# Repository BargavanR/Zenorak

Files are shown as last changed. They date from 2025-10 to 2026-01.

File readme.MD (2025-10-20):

ZENORAK_ROS2_CONTROL PACKAGE:

### Package Structure

zenorak_ros2_control/
├── config/
│ ├── controller.yaml # Controller configuration
├── description/
│ └── zenorak.xacro # Robot URDF description
├── launch/
│ ├── launch_robot.launch.py # Main robot launch file
│ └── rsp.launch.py # Robot state publisher launch
├── meshes/
│ ├── collision/ # Collision meshes
│ └── visual/ # Visual meshes
└── rviz/
└── default.rviz # RViz visualization config

## Key Components

### 1. Robot Description (`zenorak.xacro`) - Defines the physical structure of the rover:

- **Base Link**: Main chassis with mass of \_\_ kg
- **Four Wheels**: Each wheel with individual inertial properties
  - Front Left Wheel
  - Front Right Wheel
  - Rear Left Wheel
  - Rear Right Wheel
- **Joint Configuration**: Continuous joints for wheel rotation
- **Hardware Interface**: Configured for Arduino-based differential drive control

### 2. Robot State Publisher (`rsp.launch.py`) - Processes the Xacro file and publishes robot state information:

- Converts Xacro to URDF format
- Publishes TF (transform) tree for all robot links
- Provides `/robot_description` topic for visualization
- Essential for RViz and navigation stack integration

**Key Functions:**

- Reads `zenorak.xacro` from the description folder
- Processes macros into complete URDF
- Launches `robot_state_publisher` node with robot description

### 3. Main Launch File (`launch_robot.launch.py`) - Orchestrates the complete robot system startup with coordinated timing:

**Launch Sequence:**

1. **Robot State Publisher** (Immediate) - Publishes robot URDF and transforms
2. **Controller Manager** (3-second delay)

   - Manages hardware interface to Arduino
   - Loads controller configurations
   - Provides real-time control loop

3. **Differential Drive Controller** (After Controller Manager)

   - Accepts `/cmd_vel` commands
   - Controls front left and right wheels
   - Publishes odometry data

4. **Joint State Broadcaster** (After Controller Manager)
   - Publishes joint positions and velocities
   - Enables state monitoring and visualization

### 4. RViz Configuration (`default.rviz`)

Pre-configured visualization setup:

- Robot model display with collision/visual meshes
- Grid reference frame
- TF tree visualization
- Interactive tools for pose setting and measurements
- Fixed frame: `base_link`
- Orbit camera view for optimal robot observation

### Launching the Robot

# Launch complete robot system

ros2 launch zenorak_ros2_control launch_robot.launch.py

This command will:

1. Start robot state publisher
2. Initialize hardware interface (after 3-second delay)
3. Spawn differential drive controller
4. Spawn joint state broadcaster

### Controlling the Robot - Send velocity commands to the robot:

# Move forward

ros2 topic pub /diff_cont/cmd_vel_unstamped geometry_msgs/msg/Twist "{linear: {x: 0.5}, angular: {z: 0.0}}"

# Rotate in place

ros2 topic pub /diff_cont/cmd_vel_unstamped geometry_msgs/msg/Twist "{linear: {x: 0.0}, angular: {z: 0.5}}"

### Visualizing in RViz

# Launch RViz with default configuration

ros2 run rviz2 rviz2 -d $(ros2 pkg prefix zenorak_ros2_control)/share/zenorak_ros2_control/rviz/default.rviz

### Monitoring Robot State

# Check joint states

ros2 topic echo /joint_states

# Check odometry

ros2 topic echo /diff_cont/odom

# List all active controllers

ros2 control list_controllers

## Dependencies

- ROS 2 (Humble or later recommended)
- `ros2_control` and `ros2_controllers`
- `robot_state_publisher`
- `xacro`
- `rviz2`
- `diffdrive_arduino` hardware plugin
- `controller_manager`

ZENORAK_TELEOP PACKAGE:

## Features

- **Keyboard Control**: Use W, A, S, D keys for intuitive robot movement
- **Incremental Commands**: Sends progressive command values (0-120) at 1Hz
- **Non-blocking Input**: Reads keyboard in a separate thread without blocking ROS operations
- **Clean Termination**: Graceful shutdown with proper terminal restoration

## Package Structure

zenorak_teleop/
├── scripts/
│ └── zenorak_teleop.py # Main teleoperation node
├── launch/
│ └── teleop.launch.py # Launch file
├── CMakeLists.txt # Build configuration
└── package.xml # Package metadata

### Command Protocol - The node publishes to the `zenorak_teleop_cmd` topic with the following format:

| Key | Command Prefix | Direction | Example Messages |
| ----- | --- | --- | --- |
| W | `f` | Forward | `f0`, `f1`, ... `f120` |
| A | `l` | Left | `l0`, `l1`, ... `l120` |
| S | `b` | Backward  | `b0`, `b1`, ... `b120` |
| D | `r` | Right | `r0`, `r1`, ... `r120` |
| Enter | `s` | Stop | `s0` |

### Operation Flow

1. **Key Press Detection**: Continuously reads keyboard input in raw mode (no Enter needed)
2. **Counter Increment**: When a key (W/A/S/D) is held, counter increments from 0 to 120
3. **Message Publishing**: Publishes command at 1Hz (every second) while key is active
4. **Stop Command**: Pressing Enter sends `s0` and resets the system

### Dependencies

# ROS 2 packages

sudo apt install ros-<distro>-rclpy ros-<distro>-std-msgs

### Building

cd ~/ros2_ws
colcon build --packages-select zenorak_teleop
source install/setup.bash

### Method 1: Using ros2 run

ros2 run zenorak_teleop zenorak_teleop.py

### Method 2: Using Launch File

ros2 launch zenorak_teleop teleop.launch.py

### Methods Explained

**`_read_keys()`**

- Runs in separate thread
- Reads single characters from stdin
- Updates `active_key` when W/A/S/D pressed
- Sends stop command on Enter

**`_tick()`**

- Called every 1 second by ROS timer
- Publishes command if key is active
- Increments counter (0 → 120)
- Stops incrementing at 120

**`destroy_node()`**

- Stops keyboard thread
- Restores terminal settings
- Cleans up resources

ZENORAK_SERIAL PACKAGE:

## Package Structure

zenorak_serial/
├── scripts/
│ └── zenorak_serial.py # Serial bridge node
├── CMakeLists.txt # Build configuration
└── package.xml # Package metadata

### Message Processing

1. **Subscribe**: Listens to `/zenorak_teleop_cmd` topic
2. **Extract**: Gets command string from ROS message (e.g., "f25")
3. **Format**: Adds newline character for Arduino's `readStringUntil('\n')`
4. **Transmit**: Sends via serial to `/dev/ttyACM0` at 115200 baud
5. **Log**: Records successful transmission for debugging

### Serial Protocol

**Examples:**

- `f25\n` → Forward command, intensity 25
- `l10\n` → Left turn, intensity 10
- `s0\n` → Stop command

## Installation & Setup

### Dependencies

# ROS 2 packages

sudo apt install ros-<distro>-rclpy ros-<distro>-std-msgs

# Python serial library

sudo apt install python3-serial

# OR

pip3 install pyserial

### Starting the Bridge

ros2 run zenorak_serial zenorak_serial.py

### Testing Communication

**Terminal 1: Start the bridge**

```bash
ros2 run zenorak_serial zenorak_serial.py
```

**Terminal 2: Send test command**

```bash
ros2 topic pub /zenorak_teleop_cmd std_msgs/msg/String "{data: 'f50'}"
```

## Full Workflow

### 1. Hardware Setup

```bash
# Connect Arduino via USB
# Upload control firmware to Arduino
# Verify connection: ls /dev/ttyACM0
```

### 2. Launch Main Control System

```bash
# Terminal 1: Launch robot control
ros2 launch zenorak_ros2_control launch_robot.launch.py
```

### 3. Start Serial Bridge

```bash
# Terminal 2: Start Arduino bridge
ros2 run zenorak_serial zenorak_serial.py
```

### 4. Start Teleoperation

```bash
# Terminal 3: Start keyboard control
ros2 run zenorak_teleop zenorak_teleop.py
```

### 5. Control the Robot

- Use W/A/S/D keys to drive
- Press Enter to stop
- Watch RViz for visualization

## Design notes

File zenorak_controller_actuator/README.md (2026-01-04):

zenorak_controller_actuator - Full README

## Overview

`zenorak_controller_actuator` provides a ros2_control SystemInterface (hardware plugin) that bridges ROS 2 controllers to simple actuator hardware driven by a microcontroller (for example an Arduino). The package focuses on a 3-DOF linear actuator manipulator and exposes position state and position command interfaces for each actuator.

Key features

- Serial communication to a microcontroller (read ADC/potentiometer values and send actuator target counts).
- `joint_state_broadcaster` and `joint_trajectory_controller` friendly interfaces (position state + position command).
- Example URDF/ros2_control macro to include this hardware plugin into a robot description.

## Build

Build this package inside a ROS 2 workspace (source ROS 2 and use colcon):

```bash
# from the workspace root (where `src/` lives)
colcon build --packages-select zenorak_controller_actuator
source install/setup.bash
```

## Run / Launch

An example launch is provided at `bringup/launch/diffbot.launch.py`. It will:

- Expand the robot URDF/Xacro (`urdf/diffbot.urdf.xacro`) and pass it to `ros2_control_node`.
- Start the `ros2_control_node` (controller manager) with the controllers configured in `bringup/config/diffbot_controllers.yaml`.
- Spawn the `joint_state_broadcaster` and the `arm_trajectory_controller`.

To launch the example:

```bash
ros2 launch zenorak_controller_actuator diffbot.launch.py
```

If you need to remap where joint states appear, you can either update the launch file to remap `/joint_states` (recommended) or publish your own `sensor_msgs/msg/JointState` to the appropriate topic. See the docs in `docs/annotated/` for guidance on remapping.

## How it integrates into a URDF (ros2_control)

1. In your robot URDF/Xacro, include the `diffbot.ros2_control.xacro` macro (found under `description/ros2_control/`) and instantiate it with the desired joint names and parameters. Example snippet:

```xml
  <xacro:diffbot_ros2_control name="zenorak_hw" prefix="" link1_name="link_1_joint" link2_name="link_2_joint" link3_name="link_3_joint"/>
```

2. The macro sets the `<ros2_control>` `<hardware>` plugin name to `zenorak_controller_actuator/Zenorak_Hardware_Actuator`. When `ros2_control_node` loads the URDF, it will load our hardware plugin automatically.

3. Configure controllers in `bringup/config/diffbot_controllers.yaml`. Ensure joint names in the controller YAML match those provided to the URDF macro.

4. Launch the controller manager using the provided launch file or your own launch that supplies the `robot_description` parameter.

## Topics, messages and commands

- `/joint_states` (published by `joint_state_broadcaster`): `sensor_msgs/msg/JointState` containing the positions (and optionally velocities/efforts) of `link_1_joint`, `link_2_joint`, `link_3_joint`.
- Controller manager services and topics: standard ros2_control controller manager API (use `ros2 control` CLI to manage controllers).

## How other packages can use this hardware

To use this hardware plugin from another package (for example your own robot's URDF):

1. Add `zenorak_controller_actuator` as a dependency in your package.xml and CMakeLists if you reference its files directly.
2. Include the `diffbot.ros2_control.xacro` macro in your URDF or copy its pattern to your robot's `<ros2_control>` tag and set the plugin to `zenorak_controller_actuator/Zenorak_Hardware_Actuator`.
3. Provide the hardware parameters (`device`, `baud_rate`, `timeout_ms`, `link1_name`, etc.) as `<param>` entries inside the `<hardware>` tag.
4. Ensure your controllers' joint names match what the hardware will export.

Example: minimal `<ros2_control>` snippet for your URDF:

```xml
<ros2_control name="my_robot_hw" type="system">
  <hardware>
    <plugin>zenorak_controller_actuator/Zenorak_Hardware_Actuator</plugin>
    <param name="device">/dev/ttyACM0</param>
    <param name="baud_rate">115200</param>
    <param name="timeout_ms">1000</param>
    <param name="link1_name">link_1_joint</param>
    <param name="link2_name">link_2_joint</param>
    <param name="link3_name">link_3_joint</param>
  </hardware>
  <!-- per-joint entries follow -->
</ros2_control>
```

## Troubleshooting and tips

- Serial port permissions: ensure your user can open `/dev/ttyACM0` (add to `dialout` group or use `udev` rules).
- If readings look wrong: check ADC mapping parameters (`linkX_enc_val`) and the ranges used in `Actuator::potToAngle`.
- If controllers fail to start: confirm joint names match across URDF, controller YAML, and hardware plugin logs.

## Annotated sources and developer docs

Line-by-line annotated versions of key sources are available under `docs/annotated/`:

- `docs/annotated/diffbot_system.cpp.annotated.md`
- `docs/annotated/arduino_comms.hpp.annotated.md`
- `docs/annotated/Actuator.hpp.annotated.md`
- `docs/annotated/diffbot.launch.py.annotated.md`
- `docs/annotated/diffbot_controllers.yaml.annotated.md`
- `docs/annotated/diffbot.ros2_control.xacro.annotated.md`

These files explain what each line does, where it is called from, expected inputs and outputs, and production notes. Use them to onboard teammates or to adapt the code to new hardware.

## Contributing

- If you extend the serial protocol on the microcontroller, update `arduino_comms.hpp` to match the new command/response strings and update the annotated docs.
- For high-frequency or production control, consider moving serial I/O to a dedicated thread and adding robust parsing/validation of messages.

## License

This package uses the Apache 2.0 license (see headers in source files).

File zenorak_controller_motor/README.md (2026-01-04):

````markdown
# zenorak_controller_motor

A clear, well-documented ros2_control hardware plugin for a differential-drive robot that talks to a microcontroller (for example, an Arduino) over serial. This package exposes two wheel joints to ros2_control and converts between controller velocity commands and microcontroller motor counts. It also reads encoder counts from the microcontroller and publishes them as joint states via ros2_control state interfaces.

This README explains how the package is structured, how the code works, and how to integrate it into a URDF/xacro-based robot description so controllers can use it.

---

## What this package provides (high level)

- A SystemInterface implementation (the hardware plugin) that exposes the following interfaces to ros2_control:
  - left_wheel_joint: position (state), velocity (state), velocity (command)
  - right_wheel_joint: position (state), velocity (state), velocity (command)
- A tiny serial helper (`ArduinoComms`) that sends simple ASCII commands to the microcontroller and reads ASCII replies.
- Small helper classes (`Wheel`, optional `Actuator`) used to store runtime state (encoder counts, position, velocity, command).

The plugin is intended to be used with standard ROS 2 controllers (for example, `diff_drive_controller`), launched from a bringup/launch file and referenced from a URDF/xacro 'ros2_control' hardware block.

---

## Key files and what they do (developer-friendly)

- `hardware/diffbot_system.cpp` - The core hardware plugin implementation. It implements the lifecycle callbacks (`on_init`, `on_configure`, `on_activate`, `read`, `write`) used by ros2_control. This file contains the logic that:

  - reads the configuration from the `ros2_control` hardware block (serial device, baud rate, joint names, encoder counts)
  - converts encoder counts read from the microcontroller into joint positions and velocities
  - converts commanded wheel velocities into "counts per loop" and sends motor commands to the microcontroller

- `hardware/include/zenorak_controller_motor/arduino_comms.hpp` - Serial communication helper. It exposes `connect()`, `disconnect()`, `read_encoder_values()`, and `set_motor_values()`.

  - Protocol expected by microcontroller (ASCII commands):
    - `e\r` -> returns: `<left_enc> <right_enc>\n`
    - `m <left_counts> <right_counts>\r` -> set motor counts (no reply expected)

- `hardware/include/zenorak_controller_motor/wheel.hpp` - Small struct-like class used to store `name`, `enc`, `cmd`, `pos`, `vel`, and conversion factor `rads_per_count`.

- `hardware/include/zenorak_controller_motor/Actuator.hpp` - Optional helper mapping potentiometer values to angles. If your robot has no analog actuators, this file is unused but left for reference.

- `description/ros2_control/diffbot.ros2_control.xacro` - Example `ros2_control` hardware block and joint entries to include in your robot's URDF/xacro.

- `bringup/launch/diffbot.launch.py` and `bringup/config/diffbot_controllers.yaml` - Example launch and controllers configuration to run the hardware with controllers.

---

## How it works (step-by-step, plain English)

1. At startup, ROS 2 loads the hardware plugin and calls `on_init()` with parameters defined in the robot's `ros2_control` xacro/URDF hardware block.
2. The plugin stores configuration such as joint names, serial device path (e.g. `/dev/ttyACM0`), baud rate, encoder counts per revolution, and loop rate.
3. When the lifecycle transitions to `configure`, the plugin opens the serial port to the microcontroller.
4. In the running state, `read()` is called periodically by the controller manager:
   - It sends `e\r` to the microcontroller and expects two integers (left and right encoder counts).
   - It converts counts -> radians via `rads_per_count` and updates the ROS state interfaces (position & velocity).
5. Also while running, `write()` is called periodically:
   - It reads velocity commands (rad/s) from the command interfaces.
   - It converts these to counts-per-loop using `counts_per_loop = cmd / rads_per_count / loop_rate`.
   - It sends `m <left_counts> <right_counts>\r` to the microcontroller.

Output visible to the rest of ROS:

- The plugin provides state interfaces (position and velocity) which controllers and `joint_state_broadcaster` can read and publish. Controllers write velocity commands which eventually get sent to the microcontroller as motor counts.

---

## How to build

From your ROS 2 workspace root (where `src/` is located):

```bash
colcon build --packages-select zenorak_controller_motor
```
````

Source the install overlay after build:

```bash
source install/setup.bash
```

---

## Example: how to include this hardware in your URDF/xacro

Below is a minimal snippet to add to your robot xacro that tells ros2_control to use this plugin.

```xml
<ros2_control name="diffbot_hw" type="system">
	<hardware>
		<plugin>zenorak_controller_motor/Zenorak_Hardware_Motor</plugin>
		<param name="left_wheel_name">left_wheel_joint</param>
		<param name="right_wheel_name">right_wheel_joint</param>
		<param name="loop_rate">10</param>
		<param name="device">/dev/ttyACM0</param>
		<param name="baud_rate">115200</param>
		<param name="timeout_ms">1000</param>
		<param name="enc_counts_per_rev">32</param>
	</hardware>

	<!-- define the two wheel joints and their interfaces -->
	<joint name="left_wheel_joint">
		<command_interface name="velocity"/>
		<state_interface name="position"/>
		<state_interface name="velocity"/>
	</joint>
	<joint name="right_wheel_joint">
		<command_interface name="velocity"/>
		<state_interface name="position"/>
		<state_interface name="velocity"/>
	</joint>
</ros2_control>
```

Notes:

- `loop_rate` must match the control loop frequency (how often `read()`/`write()` are called).
- `enc_counts_per_rev` must match your encoder hardware.

---

## Example controller configuration

In `bringup/config/diffbot_controllers.yaml` you'll typically have a `diff_drive_controller` and broadcaster entries. Example:

```yaml
controller_manager:
	ros__parameters:
		update_rate: 50

joint_state_broadcaster:
	ros__parameters:
		use_sim_time: false

diff_drive_controller:
	ros__parameters:
		left_wheel: left_wheel_joint
		right_wheel: right_wheel_joint
		wheel_separation: 0.5
		wheel_radius: 0.1
		cmd_vel_timeout: 0.5
```

Adjust `wheel_separation` and `wheel_radius` to your robot.

---

## How to run (basic)

1. Build and source your workspace.
2. Launch your robot description (URDF/xacro) that contains the `ros2_control` block referencing this plugin. Example (adjust paths):

```bash
ros2 launch zenorak_controller_motor bringup/launch/diffbot.launch.py
```

3. Start controllers (example using ros2 control CLI):

```bash
# list available controllers
ros2 control list_controllers
# load and start joint_state_broadcaster and diff_drive_controller as appropriate
ros2 control load_start_controller joint_state_broadcaster
ros2 control load_start_controller diff_drive_controller
```

4. Publish velocity commands (example):

```bash
ros2 topic pub /cmd_vel geometry_msgs/msg/Twist '{linear: {x: 0.1}, angular: {z: 0.0}}' -r 10
```

You should see the microcontroller receive `m <left> <right>` commands and the `joint_states` topic reflect wheel positions.

---

## Microcontroller (Arduino) expectations

This plugin uses a simple ASCII protocol. The microcontroller firmware should implement at least:

- On receiving `e\r` respond with: `<left_enc> <right_enc>\n` (two signed integers and a newline).
- On receiving `m <left> <right>\r` set motor speed/position accordingly (no response required).

A robust microcontroller implementation should also handle invalid input gracefully and send timely responses.

---

## Troubleshooting

- If the plugin fails to configure, check that the serial device exists and that you have permission to open it.
- If you see timeouts, increase `timeout_ms` in the ros2_control hardware params or debug the microcontroller firmware to ensure it replies.
- Use `ros2 topic echo /joint_states` to inspect published wheel positions.

---

## Developer notes (production-friendly comments)

- The hardware plugin is intentionally small and synchronous. For production systems, consider:

  - Offloading serial reads/writes to a dedicated thread and using lock-free buffers for real-time safety.
  - Adding better error handling and health reporting for serial comms.
  - Instrumentation for latency and packet loss.

- This package keeps logic simple so it is easy to adapt the serial protocol if your microcontroller uses different messages.

---

## License

Licensed under Apache-2.0 (same as upstream ros2_control demos).

**_ End of README _**

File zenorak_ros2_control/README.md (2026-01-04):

# zenorak_ros2_control — ROS 2 Control (Quick Reference)

This document is a concise reference for the `zenorak_ros2_control` package. It explains what the bundle of launch files starts, which controllers are spawned, the most important topics you will use to send commands and read feedback, useful example commands (trajectory and teleop), and some troubleshooting tips.

Keep this README handy when running demos or handing off the code to other team members.

Usb path arduino for the servo and force : lrwxrwxrwx 1 root root 13 Jan  2 18:07 /dev/serial/by-path/platform-3610000.usb-usb-0:2.2.1:1.0 -> ../../ttyACM1

## Quick summary

- Primary launch file: `launch/launch_robot.launch.py`
- Includes: `launch/rsp.launch.py` (robot_state_publisher + URDF)
- Controller manager: `ros2_control_node` (started via `controller_manager` package)
- Controllers spawned automatically by the launch: `diff_cont`, `joint_broad`, `arm_trajectory_controller`,'joint_state_broadcaster'

## What runs when you run the main launch

Command to start everything (from the workspace root after sourcing the workspace):

```bash
source install/setup.bash
ros2 launch zenorak_ros2_control launch_robot.launch.py
```

What this does (high level):

- Starts `robot_state_publisher` (from `rsp.launch.py`) which publishes the robot TFs and the `robot_description` parameter (URDF).
- Starts `ros2_control_node` (controller_manager) with the robot description and controller configuration YAMLs.
- Spawns controllers using `controller_manager` spawner tools after the controller manager is up:
  - `diff_cont` — differential-drive velocity controller (subscribes to cmd_vel-like topic)
  - `joint_broad` — joint state broadcaster (publishes `/joint_states`)
  - `arm_trajectory_controller` — trajectory-based controller for the manipulator arm
  - 'joint_state_broadcaster' - Joint State broadcaster for the overall feedback for actuator

The launch script delays the controller manager start briefly so the `robot_description` is available and registers event handlers so controllers are spawned only after the controller manager is running.

## Important topics (command & feedback)

Control topics (what you send to):

- `/arm_trajectory_controller/joint_trajectory` [trajectory_msgs/msg/JointTrajectory]
  - Send joint trajectories to the arm controller.
- `/diff_cont/cmd_vel_unstamped` [geometry_msgs/msg/Twist]
  - Velocity commands for the differential drive controller (diff_cont).

Feedback topics (what you read from):

- `/arm_trajectory_controller/state` [control_msgs/msg/JointTrajectoryControllerState]
  - State & feedback from the arm trajectory controller.
- `/diff_cont/odom` [nav_msgs/msg/Odometry]
  - Odometry from the differential drive controller / hardware interface.
- `/joint_states` [sensor_msgs/msg/JointState]
  - Consolidated joint positions/velocities/efforts (published by `joint_broad`).
- `/robot_description` [std_msgs/msg/String]
  - The URDF/XML published by `robot_state_publisher` (useful for diagnostics or confirming the loaded robot model).

You can list topics and types with:

```bash
ros2 topic list
ros2 topic list -t
```

And echo a topic to inspect messages:

```bash
ros2 topic echo /joint_states
ros2 topic echo /diff_cont/odom
ros2 topic echo /arm_trajectory_controller/state
```

## Example commands

1. Publish a one-shot joint trajectory to move the arm (example you already used):

```bash
ros2 topic pub --once /arm_trajectory_controller/joint_trajectory trajectory_msgs/msg/JointTrajectory "
joint_names:
- linkk_1
- link_2
- link_3
points:
- positions: [0.0, 80.0, 0.0]
  time_from_start:
    sec: 0
"
```

Notes:

- The `joint_names` must match the joints used by the controller (check `/joint_states` for naming).
- `time_from_start` = 0 makes this a position setpoint; for smooth motion provide a non-zero time.

2. Run teleop for driving the base (remap cmd_vel to the controller topic):

```bash
ros2 run teleop_twist_keyboard teleop_twist_keyboard --ros-args -r /cmd_vel:=/diff_cont/cmd_vel_unstamped
```

This remaps the `teleop_twist_keyboard` default `/cmd_vel` to the controller's `/diff_cont/cmd_vel_unstamped` topic.

3. Spawn or stop a controller manually (if you need to):

- Spawn (alternative to automatic spawner):

```bash
ros2 run controller_manager spawner diff_cont
ros2 run controller_manager spawner arm_trajectory_controller
```

- To stop/unload a controller use the spawner with the `--stopped` flag (or use the controller manager services):

```bash
ros2 run controller_manager spawner --stopped diff_cont
```

If you prefer services, the controller manager exposes service calls such as `/controller_manager/list_controllers` and `/controller_manager/spawn_controller` (useful for scripts).

## How to verify controllers are running

- Check controller topics and feedback:

```bash
ros2 topic list -t
ros2 topic echo /arm_trajectory_controller/state
ros2 topic echo /diff_cont/odom
ros2 topic echo /joint_states
```

- Watch controller manager logs (in the terminal where the launch was run). The spawner prints messages when controllers are started.
- Use `ros2 service list` and check `/controller_manager/*` services for lifecycle & management operations.

## Troubleshooting

- Error: "Unable to parse the value of parameter robot_description as yaml"
  - Cause: `robot_description` contains URDF/XML which the ROS 2 launch parameter loader may try to parse as YAML. XML has characters that confuse the YAML parser.
  - Solution: ensure launch files pass the URDF as a raw string. Example fix we applied in `launch/rsp.launch.py` and `launch/launch_robot.launch.py`:

```python
from launch_ros.parameter_descriptions import ParameterValue
robot_description = Command(['ros2 param get --hide-type /robot_state_publisher robot_description'])
params = {'robot_description': ParameterValue(robot_description, value_type=str)}
```

- If you see that error, check the launch file(s) that set `robot_description` and wrap the value in `ParameterValue(..., value_type=str)`.

- If controllers fail to spawn:
  - Confirm `ros2_control_node` is running and has loaded the controller YAMLs.
  - Check log output from the spawner node; it will indicate why a controller failed to start (missing hardware interface, parameter errors, missing joints, etc.).

## Helpful quick commands

- Source workspace:

```bash
source install/setup.bash
```

- Launch the robot + controllers:

```bash
ros2 launch zenorak_ros2_control launch_robot.launch.py
```

- Echo a topic:

```bash
ros2 topic echo /joint_states
```

- Spawn a controller manually:

```bash
ros2 run controller_manager spawner arm_trajectory_controller
```

# Programmatic examples for zenorak_ros2_control

This file contains short Python examples showing how to call key behaviors from code.

## 1) Publish a one-shot JointTrajectory to `/arm_trajectory_controller/joint_trajectory` using rclpy

```python
#!/usr/bin/env python3
import rclpy
from rclpy.node import Node
from trajectory_msgs.msg import JointTrajectory, JointTrajectoryPoint

def send_one_shot_trajectory():
    rclpy.init()
    node = Node('traj_pub')
    pub = node.create_publisher(JointTrajectory, '/arm_trajectory_controller/joint_trajectory', 10)

    msg = JointTrajectory()
    msg.joint_names = ['linkk_1', 'link_2', 'link_3']
    point = JointTrajectoryPoint()
    point.positions = [0.0, 80.0, 0.0]
    # time_from_start=0 -> immediate setpoint; use non-zero for smooth motion
    point.time_from_start.sec = 0
    msg.points = [point]

    # publish once
    pub.publish(msg)
    node.get_logger().info('Published one-shot JointTrajectory')

    # give the middleware a short time to send
    rclpy.spin_once(node, timeout_sec=0.5)
    node.destroy_node()
    rclpy.shutdown()

if __name__ == '__main__':
    send_one_shot_trajectory()
```

## 2) Publish a Twist to drive the base programmatically

```python
#!/usr/bin/env python3
import rclpy
from rclpy.node import Node
from geometry_msgs.msg import Twist

def send_twist(linear_x=0.2, angular_z=0.0):
    rclpy.init()
    node = Node('twist_pub')
    pub = node.create_publisher(Twist, '/diff_cont/cmd_vel_unstamped', 10)

    t = Twist()
    t.linear.x = float(linear_x)
    t.angular.z = float(angular_z)

    pub.publish(t)
    node.get_logger().info(f'Published Twist linear.x={linear_x} angular.z={angular_z}')
    rclpy.spin_once(node, timeout_sec=0.2)
    node.destroy_node()
    rclpy.shutdown()

if __name__ == '__main__':
    send_twist(0.2, 0.1)
```

## 3) Spawn a controller from Python (calls the `spawner` executable)

```python
#!/usr/bin/env python3
import subprocess

def spawn_controller(controller_name: str):
    # This blocks until the spawner process finishes; it prints logs to stdout/stderr.
    subprocess.run(['ros2', 'run', 'controller_manager', 'spawner', controller_name], check=True)

if __name__ == '__main__':
    spawn_controller('diff_cont')
```

Notes:

- The rclpy examples assume your ROS_DOMAIN_ID and environment are set appropriately and you have sourced your workspace where nodes are running.
- For programmatic controller management using services, you can call controller manager services (`/controller_manager/list_controllers`, `/controller_manager/switch_controller`, etc.) via rclpy — that requires the controller_manager_msgs service types and slightly more boilerplate, so the spawner subprocess is a quick option.

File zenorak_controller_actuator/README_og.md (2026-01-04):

# zenorak_controller_actuator

zenorak_controller_actuator provides a ros2_control system hardware interface for a mobile robot with a differential-drive base and a 3-DOF linear-actuated manipulator.

The hardware interface communicates with a microcontroller (e.g. Arduino) over a serial connection and is designed to work with standard ROS 2 controllers such as diff_drive_controller, joint_state_broadcaster, and joint_trajectory_controller.
It is based on the diffbot example from [ros2_control demos](https://github.com/ros-controls/ros2_control_demos/tree/master/example_2).

For a tutorial on how to develop a hardware interface like this, check out the video below:

https://youtu.be/J02jEKawE5U

## To Do

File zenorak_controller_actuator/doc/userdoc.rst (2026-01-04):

.. _ros2_control_demos_example_2_userdoc:

*********
DiffBot
*********

*DiffBot*, or ''Differential Mobile Robot'', is a simple mobile base with differential drive.
The robot is basically a box moving according to differential drive kinematics.

For *example_2*, the hardware interface plugin is implemented having only one interface.

- The communication is done using proprietary API to communicate with the robot control box.
- Data for all joints is exchanged at once.

The *DiffBot* URDF files can be found in ``description/urdf`` folder.

Tutorial steps
--------------------------

1. To check that *DiffBot* description is working properly use following launch commands

   .. code-block:: shell

    ros2 launch zenorak_controller_actuator view_robot.launch.py

   .. warning::
    Getting the following output in terminal is OK: ``Warning: Invalid frame ID "odom" passed to canTransform argument target_frame - frame does not exist``.
    This happens because ``joint_state_publisher_gui`` node need some time to start.

Differential Mobile Robot
   

2. To start *DiffBot* example open a terminal, source your ROS2-workspace and execute its launch file with

   .. code-block:: shell

    ros2 launch zenorak_controller_actuator diffbot.launch.py

   The launch file loads and starts the robot hardware, controllers and opens *RViz*.
   In the starting terminal you will see a lot of output from the hardware implementation showing its internal states.
   This excessive printing is only added for demonstration. In general, printing to the terminal should be avoided as much as possible in a hardware interface implementation.

   If you can see an orange box in *RViz* everything has started properly.
   Still, to be sure, let's introspect the control system before moving *DiffBot*.

3. Check if the hardware interface loaded properly, by opening another terminal and executing

   .. code-block:: shell

    ros2 control list_hardware_interfaces

   You should get

   .. code-block:: shell

    command interfaces
          left_wheel_joint/velocity [available] [claimed]
          right_wheel_joint/velocity [available] [claimed]
    state interfaces
          left_wheel_joint/position
          left_wheel_joint/velocity
          right_wheel_joint/position
          right_wheel_joint/velocity

   The ``[claimed]`` marker on command interfaces means that a controller has access to command *DiffBot*.

4. Check if controllers are running

   .. code-block:: shell

    ros2 control list_controllers

   You should get

   .. code-block:: shell

    diffbot_base_controller[diff_drive_controller/DiffDriveController] active
    joint_state_broadcaster[joint_state_broadcaster/JointStateBroadcaster] active

5. If everything is fine, now you can send a command to *Diff Drive Controller* using ROS 2 CLI interface:

   .. code-block:: shell

    ros2 topic pub --rate 30 /diffbot_base_controller/cmd_vel_unstamped geometry_msgs/msg/Twist "linear:
      x: 0.7
      y: 0.0
      z: 0.0
    angular:
      x: 0.0
      y: 0.0
      z: 1.0"

   You should now see an orange box circling in *RViz*.
   Also, you should see changing states in the terminal where launch file is started.

   .. code-block:: shell

    [Zenorak_Hardware_Actuator]: Got command 43.33333 for 'left_wheel_joint'!
    [Zenorak_Hardware_Actuator]: Got command 50.00000 for 'right_wheel_joint'!

Files used for this demos
#########################

  - Launch file: `diffbot.launch.py <https://github.com/ros-controls/ros2_control_demos/tree/master/example_2/bringup/launch/diffbot.launch.py>`__
  - Controllers yaml: `diffbot_controllers.yaml <https://github.com/ros-controls/ros2_control_demos/tree/master/example_2/bringup/config/diffbot_controllers.yaml>`__
  - URDF file: `diffbot.urdf.xacro <https://github.com/ros-controls/ros2_control_demos/tree/master/example_2/description/urdf/diffbot.urdf.xacro>`__

    + Description: `diffbot_description.urdf.xacro <https://github.com/ros-controls/ros2_control_demos/tree/master/example_2/description/urdf/diffbot_description.urdf.xacro>`__
    + ``ros2_control`` tag: `diffbot.ros2_control.xacro <https://github.com/ros-controls/ros2_control_demos/tree/master/example_2/description/ros2_control/diffbot.ros2_control.xacro>`__

  - RViz configuration: `diffbot.rviz <https://github.com/ros-controls/ros2_control_demos/tree/master/example_2/description/rviz/diffbot.rviz>`__

  - Hardware interface plugin: `diffbot_system.cpp <https://github.com/ros-controls/ros2_control_demos/tree/master/example_2/hardware/diffbot_system.cpp>`__

Controllers from this demo
##########################

- ``Joint State Broadcaster`` (`ros2_controllers repository <https://github.com/ros-controls/ros2_controllers/tree/master/joint_state_broadcaster>`__): `doc <https://control.ros.org/master/doc/ros2_controllers/joint_state_broadcaster/doc/userdoc.html>`__
- ``Diff Drive Controller`` (`ros2_controllers repository <https://github.com/ros-controls/ros2_controllers/tree/master/diff_drive_controller>`__): `doc <https://control.ros.org/master/doc/ros2_controllers/diff_drive_controller/doc/userdoc.html>`__

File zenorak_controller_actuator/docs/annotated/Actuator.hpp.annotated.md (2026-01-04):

# Annotated: Actuator.hpp

This document annotates the `Actuator` helper class. It explains every logical line/block and shows where each method is used.

---

```cpp
#ifndef ZENORAK_CONTROLLER_ACTUATOR_ACTUATOR_HPP
#define ZENORAK_CONTROLLER_ACTUATOR_ACTUATOR_HPP
```

- Include guard to prevent duplicate inclusion.

```cpp
#include <string>
#include <cmath>
```

- Includes for std::string and math helpers.

```cpp
inline double clamp(double val, double min_val, double max_val)
{
  if (val < min_val) return min_val;
  if (val > max_val) return max_val;
  return val;
}
```

- Small utility to clamp a floating value between limits. Used by `angleToPot` and `potToAngle`.

```cpp
class Actuator
{
    public:

    std::string name = "";
    int raw_count = 0; // raw potentiometer/encoder reading from Arduino
    double cmd = 0;
    double pos = 0;
    double vel = 0;
    double rads_per_count = 0;
    int counts_per_rev = 1; // divider to compute rads_per_count
```

- Data members:
  - `name`: joint name used when declaring interfaces.
  - `raw_count`: last raw ADC/encoder reading from microcontroller.
  - `cmd`: command value written by controllers (position in this package).
  - `pos` and `vel`: current state values exported to ros2_control.
  - `rads_per_count` and `counts_per_rev`: conversion constants for encoders (if used).

```cpp
    Actuator() = default;

    Actuator(const std::string &link_name)
    {
      setup(link_name);
    }

    void setup(const std::string &link_name)
    {
      name = link_name;

    }
```

- Constructors and `setup` method: `setup` assigns a friendly joint name and could be extended to compute conversion factors.

```cpp
    double calc_enc_angle()
    {
      return raw_count * rads_per_count;
    }
```

- Convert a raw encoder count to an angle in radians using `rads_per_count`.

```cpp
    int angleToPot(double theta,
                  double logical_min_deg, double logical_max_deg,
                  int pot_min, int pot_max)
    {

      theta = clamp(theta, logical_min_deg, logical_max_deg);

      double ratio =
        (theta - logical_min_deg) / (logical_max_deg - logical_min_deg);

      return static_cast<int>(pot_min + ratio * (pot_max - pot_min));
    }
```

- Map a logical angle in degrees to a hardware potentiometer range (integer counts).
- Usage: called by `diffbot_system.cpp::write()` to convert `Actuator.cmd` into `a1_target` etc.

```cpp
    double potToAngle(int pot_value,
                      double logical_min_deg, double logical_max_deg,
                      int pot_min, int pot_max)
    {
      // Clamp raw pot to safe range
      pot_value = static_cast<int>(
        clamp(static_cast<double>(pot_value),
              static_cast<double>(pot_min),
              static_cast<double>(pot_max)));

      // Normalize (0 → 1)
      double ratio =
        static_cast<double>(pot_value - pot_min) /
        static_cast<double>(pot_max - pot_min);

      // Scale to logical angle (degrees)
      double theta_deg =
        logical_min_deg + ratio * (logical_max_deg - logical_min_deg);

      // Degrees → radians
      return theta_deg ;
    }
```

- Convert a potentiometer count (ADC) into a logical angle in degrees.
- Note: this function returns degrees as written; if radians are required, multiply by `M_PI/180.0` externally or update here.

```cpp
#endif // ZENORAK_CONTROLLER_ACTUATOR_WHEEL_HPP
```

Cross references:

- `angleToPot` used in `hardware/diffbot_system.cpp::write()` to compute target counts.
- `potToAngle` used in `hardware/diffbot_system.cpp::read()` to convert raw ADC readings to logical joint positions.

Production summary:

- `Actuator` is a tiny data-and-conversion helper. It keeps the last raw reading and computes friendly positions and velocities that the hardware interface exports to ROS controllers. It's intentionally simple so you can adapt the mapping parameters to your specific potentiometer or encoder.

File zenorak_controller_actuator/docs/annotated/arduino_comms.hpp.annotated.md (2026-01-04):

# Annotated: arduino_comms.hpp

This document contains the original `arduino_comms.hpp` contents with friendly, detailed explanations for each section/line, plus cross-references to where functions are used.

---

```cpp
#ifndef ZENORAK_CONTROLLER_ACTUATOR_ARDUINO_COMMS_HPP
#define ZENORAK_CONTROLLER_ACTUATOR_ARDUINO_COMMS_HPP
```

- Standard C++ include guard to prevent double inclusion at compile time.

```cpp
#include <sstream>
#include <libserial/SerialPort.h>
#include <iostream>
```

- Includes for string streams (to build messages), LibSerial for serial comms, and iostream for debug prints.

```cpp
LibSerial::BaudRate convert_baud_rate(int baud_rate)
{
  switch (baud_rate)
  {
    case 1200: return LibSerial::BaudRate::BAUD_1200;
    ...
    default:
      std::cout << "Error! Baud rate " << baud_rate << " not supported! Default to 57600" << std::endl;
      return LibSerial::BaudRate::BAUD_57600;
  }
}
```

- What it is: small helper that maps an integer baud rate (e.g., 115200) into LibSerial's enum type.
- Where used: called in `connect()` to set serial speed.

```cpp
class ArduinoComms
{
public:
  ArduinoComms() = default;

  void connect(const std::string &serial_device, int32_t baud_rate, int32_t timeout_ms)
  {
    timeout_ms_ = timeout_ms;
    serial_conn_.Open(serial_device);
    serial_conn_.SetBaudRate(convert_baud_rate(baud_rate));
  }
```

- What it is: `connect` opens the serial device path (e.g., `/dev/ttyACM0`) and sets the baud rate. It stores the timeout for future reads.
- Syntax: `serial_conn_.Open(...)` uses LibSerial API.
- Where called: `on_configure()` in `diffbot_system.cpp`.

```cpp
  void disconnect()
  {
    serial_conn_.Close();
  }

  bool connected() const
  {
    return serial_conn_.IsOpen();
  }
```

- Simple wrappers to close the serial port and check if it's open.

```cpp
  void send_only(const std::string &msg)
  {
    serial_conn_.Write(msg);
  }
```

- Send bytes to Arduino without expecting a reply.

```cpp
  bool send_msg(const std::string &msg_to_send, std::string &response)
{
  try
  {
    serial_conn_.Write(msg_to_send);
    serial_conn_.ReadLine(response, '\n', timeout_ms_);
    return true;   // success
  }
  catch (const LibSerial::ReadTimeout&)
  {
    return false;  // timeout happened
  }
}
```

- What it is: send a message then block until a newline-terminated response or timeout. Returns `true` if response received.
- Where used: `read_actuator_values` uses this to request `a\r` and parse returned counts.

```cpp
  bool read_actuator_values(int &val_1, int &val_2, int &val_3)
  {
    std::string response;
    bool ok = send_msg("a\r", response);

    if (!ok) {
      return false;
    }

    std::stringstream ss(response);
    ss >> val_1 >> val_2 >> val_3;
    return true;
  }
```

- What it is: request three actuator ADC counts from the Arduino. The Arduino is expected to reply with a space-separated line like `512 600 450\n`.
- Output: sets `val_1..3` to parsed integers; returns true when successful.
- Where it's used: called by `Zenorak_Hardware_Actuator::read()` to update actuator readings.

```cpp
  void set_actuator_positions(int val_1, int val_2, int val_3)
  {
    std::stringstream ss;
    ss << "s " << val_1 << " " << val_2 << " " << val_3 << "\r";
    send_only(ss.str());
  }
```

- What it is: send an `s v1 v2 v3\r` message to the Arduino to command actuator positions in hardware counts.
- Where it's used: `Zenorak_Hardware_Actuator::write()` constructs targets and calls this method.

```cpp
  void set_pid_values(int k_p, int k_d, int k_i, int k_o)
  {
    std::stringstream ss;
    ss << "u " << k_p << ":" << k_d << ":" << k_i << ":" << k_o << "\r";
    // send_msg(ss.str());
  }
```

- This prepares a PID set-string. The actual send is commented out; you may enable `send_msg` if the microcontroller supports and responds to this command.

```cpp
private:
    LibSerial::SerialPort serial_conn_;
    int timeout_ms_;
};

#endif // ZENORAK_CONTROLLER_ACTUATOR_ARDUINO_COMMS_HPP
```

- Private members hold the serial port object and configured read timeout (ms).

Cross references summary:

- `read_actuator_values` is used in `hardware/diffbot_system.cpp::read()` to obtain current measurement values.
- `set_actuator_positions` is used in `hardware/diffbot_system.cpp::write()` to send actuator commands.

Production notes:

- This class is a small, synchronous protocol layer to an Arduino. In production, consider making reads non-blocking or using a dedicated I/O thread to avoid blocking the real-time control loop.
- Validate Arduino replies to detect malformed lines.

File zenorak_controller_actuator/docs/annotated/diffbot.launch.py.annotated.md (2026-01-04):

# Annotated: diffbot.launch.py

This file launches the `ros2_control_node` and spawners for controllers used by the package. Below we explain the important parts and how the broadcaster/controller spawners work.

```python
# Copyright 2020 ros2_control Development Team
# (License header omitted for brevity in this annotated view)

from launch import LaunchDescription
from launch.actions import RegisterEventHandler
from launch.event_handlers import OnProcessExit
from launch.substitutions import Command, FindExecutable, PathJoinSubstitution

from launch_ros.actions import Node
from launch_ros.substitutions import FindPackageShare
from launch_ros.parameter_descriptions import ParameterValue
```

- Imports: these bring in ROS 2 launch primitives used to build the launch description that starts multiple nodes together.

```python
def generate_launch_description():
    # Get URDF via xacro
    robot_description_content = Command([
            PathJoinSubstitution([FindExecutable(name="xacro")]),
            " ",
            PathJoinSubstitution([
                FindPackageShare("zenorak_controller_actuator"), "urdf", "diffbot.urdf.xacro"]),
        ])
    robot_description = {"robot_description": ParameterValue(robot_description_content, value_type=str)}
```

- What it is: expands the `diffbot.urdf.xacro` into a plain URDF string at launch time and passes it as the `robot_description` parameter. This is a common ROS pattern to avoid creating static URDF files.

```python
    robot_controllers = PathJoinSubstitution([
        FindPackageShare("zenorak_controller_actuator"),
        "config",
        "diffbot_controllers.yaml",
    ])
```

- Path to controller config YAML used by controller_manager.

```python
    control_node = Node(
        package="controller_manager",
        executable="ros2_control_node",
        parameters=[robot_description, robot_controllers],
        output="both",
    )
```

- Starts `ros2_control_node` (the controller manager) with the URDF and controller YAML. This node will load the hardware plugin specified in the URDF and then create joint state and trajectory controllers according to the YAML.

```python
    joint_state_broadcaster_spawner = Node(
        package="controller_manager",
        executable="spawner",
        arguments=["joint_state_broadcaster", "--controller-manager", "/controller_manager"],
    )
```

- `spawner` is a helper executable that requests the controller manager to load and start a controller by name. This line spawns `joint_state_broadcaster` which publishes `/joint_states` (or the remapped topic if you adjusted it) using the state interfaces exported by the hardware.

```python
    arm_trajectory_spawner = Node(
        package="controller_manager",
        executable="spawner",
        arguments=["arm_trajectory_controller", "--controller-manager", "/controller_manager"],
    )
```

- Spawns the group trajectory controller that accepts position commands for the manipulator joints.

```python
    nodes = [
        control_node,
       # robot_state_pub_node,
        joint_state_broadcaster_spawner,
       # delay_rviz_after_joint_state_broadcaster_spawner,
       arm_trajectory_spawner,
    ]

    return LaunchDescription(nodes)
```

- The LaunchDescription returns the list of nodes/actions launched by this file. When you run `ros2 launch zenorak_controller_actuator diffbot.launch.py` these nodes are started in the given order.

Cross references:

- `robot_description` is built from `urdf/diffbot.urdf.xacro` which contains the `<ros2_control>` plugin and joint definitions.
- `diffbot_controllers.yaml` defines the `joint_state_broadcaster` and `arm_trajectory_controller` behavior (see annotated YAML file).

Production notes and tips:

- To remap topics or pass launch arguments, you can edit this file to declare `DeclareLaunchArgument` and use `LaunchConfiguration` to apply remappings to nodes. For example, remapping `/joint_states` published by the broadcaster can be performed at the ros2_control_node level or by remapping subscriber topics downstream.
- If the controller spawner fails to start controllers, check the controller_manager logs (`ros2 topic echo /controller_manager/list_controllers`) and ensure joint names in URDF match those in controllers YAML.

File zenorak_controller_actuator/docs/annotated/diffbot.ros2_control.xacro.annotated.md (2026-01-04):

# Annotated: diffbot.ros2_control.xacro

This file contains the `<ros2_control>` system definition used by the URDF/Xacro to tell `ros2_control_node` which plugin to load and which joints to export. Below are line-level explanations and usage notes.

```xml
<?xml version="1.0"?>
<robot xmlns:xacro="http://www.ros.org/wiki/xacro">

  <xacro:macro name="diffbot_ros2_control" params="name prefix link1_name='link_1_joint' link2_name='link_2_joint' link3_name='link_3_joint'">

    <ros2_control name="${name}" type="system">
      <hardware>
        <plugin>zenorak_controller_actuator/Zenorak_Hardware_Actuator</plugin>
```

- What it is: Declares the hardware plugin that the controller manager should load. The string `zenorak_controller_actuator/Zenorak_Hardware_Actuator` corresponds to the pluginlib export in `diffbot_system.cpp` (PLUGINLIB_EXPORT_CLASS).
- Where this string is used: `ros2_control_node` reads this tag and uses pluginlib to construct the hardware system.

```xml
        <!-- Wheel/motor parameters removed - only actuator params kept -->
        <param name="device">/dev/ttyACM0</param>
        <param name="baud_rate">115200</param>
        <param name="timeout_ms">1000</param>
        <!-- enc_counts_per_rev removed -->
        <param name="pid_p">20</param>
        <param name="pid_d">12</param>
        <param name="pid_i">0</param>
        <param name="pid_o">50</param>
```

- These parameters are read by `Zenorak_Hardware_Actuator::on_init()` and used to configure the `ArduinoComms` and PID settings.

```xml
        <param name="link1_name">${link1_name}</param>
        <param name="link2_name">${link2_name}</param>
        <param name="link3_name">${link3_name}</param>
        <param name="link1_enc_val">1023</param>
        <param name="link2_enc_val">1023</param>
        <param name="link3_enc_val">1023</param>
```

- `linkX_enc_val` are the ADC full-scale values (e.g., 10-bit ADC = 1023) used in `Actuator.setup` or conversion logic.

```xml
      </hardware>

      <!-- Manipulator joints: these should match the joint names in your robot URDF/xacro -->
      <joint name="${prefix}${link1_name}">
        <command_interface name="position"/>
        <state_interface name="position"/>
      </joint>

      <joint name="${prefix}${link2_name}">
        <command_interface name="position"/>
        <state_interface name="position"/>
      </joint>

      <joint name="${prefix}${link3_name}">
        <command_interface name="position"/>
        <state_interface name="position"/>
      </joint>
```

- These `<joint>` entries are how ros2_control knows which joints to expose and which interfaces to expect. Names must match the actual joint elements used elsewhere in your URDF (the physical joint frames).

Cross references:

- The plugin name corresponds to the `PLUGINLIB_EXPORT_CLASS` macro in `hardware/diffbot_system.cpp`.
- `link1_name`, `link2_name`, `link3_name` must match joint names used in `urdf/diffbot_description.urdf.xacro`.

Production guidance:

- When you instantiate this macro in your URDF (for example, in `diffbot.urdf.xacro`), pass a unique prefix if you have multiple robots in the same ROS graph to avoid joint name collisions.
- Keep param names consistent if you write scripts to generate robot descriptions programmatically.

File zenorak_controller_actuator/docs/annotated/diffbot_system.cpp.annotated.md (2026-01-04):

# Annotated: diffbot_system.cpp

This document contains the original source lines from `hardware/diffbot_system.cpp` with friendly, line-level explanations, cross-references, and a production summary at the end.

---

```cpp
// Copyright 2021 ros2_control Development Team
//
// Licensed under the Apache License, Version 2.0 (the "License");
// you may not use this file except in compliance with the License.
// You may obtain a copy of the License at
//
//     http://www.apache.org/licenses/LICENSE-2.0
//
// Unless required by applicable law or agreed to in writing, software
// distributed under the License is distributed on an "AS IS" BASIS,
// WITHOUT WARRANTIES OR CONDITIONS OF ANY KIND, either express or implied.
// See the License for the specific language governing permissions and
// limitations under the License.
```

Explanation:

- These first block comments are the standard Apache 2.0 license header. They are metadata and do not affect runtime.

```cpp
#include "zenorak_controller_actuator/diffbot_system.hpp"
```

- What it is: C++ preprocessor include that pulls in the corresponding header for this implementation file.
- Syntax: `#include "path/to/header.hpp"` includes a header from the project include path.
- Where used next: This header declares the `Zenorak_Hardware_Actuator` class and types used below.
- Called again in: The header itself is self-contained; other files may include it if they need the class declaration.
- Output: No runtime output; this line allows compilation to find declarations.

```cpp
#include <chrono>
#include <cmath>
#include <limits>
#include <memory>
#include <vector>

#include "hardware_interface/types/hardware_interface_type_values.hpp"
#include "rclcpp/rclcpp.hpp"
```

- What it is: Standard library and ROS2 includes for time, math, containers and ROS logging.
- Syntax: `#include <...>` for system headers; `#include "..."` for project headers.
- Where used next: chrono used for sleeps and durations; rclcpp for logging and node utilities.

```cpp
namespace zenorak_controller_actuator
{
```

- What it is: Start of the package namespace. Namespaces prevent symbol collisions.

```cpp
hardware_interface::CallbackReturn Zenorak_Hardware_Actuator::on_init(
  const hardware_interface::HardwareInfo & info)
{
```

- What it is: Definition of the `on_init` method for the hardware interface class. This method is called by ros2_control when the hardware plugin is initialized.
- Syntax: C++ method definition for `Zenorak_Hardware_Actuator` class returning a `CallbackReturn`.
- Where it is called: Called by the ros2_control lifecycle when the system interface is loaded (via `controller_manager` / `ros2_control_node`).
- Output: Returns SUCCESS or ERROR to indicate initialization success.

```cpp
  if (
    hardware_interface::SystemInterface::on_init(info) !=
    hardware_interface::CallbackReturn::SUCCESS)
  {
    return hardware_interface::CallbackReturn::ERROR;
  }
```

- What it is: Calls the base class `on_init` implementation and checks for success. If the base init fails, return an error.
- Why: Ensures basic initialization performed by the SystemInterface is honored.

```cpp
  // Device and communication parameters
  cfg_.device = info_.hardware_parameters["device"];
  cfg_.baud_rate = std::stoi(info_.hardware_parameters["baud_rate"]);
  cfg_.timeout_ms = std::stoi(info_.hardware_parameters["timeout_ms"]);
  cfg_.link1_name = info_.hardware_parameters["link1_name"];
  cfg_.link2_name = info_.hardware_parameters["link2_name"];
  cfg_.link3_name = info_.hardware_parameters["link3_name"];
```

- What it is: Reads hardware parameters from the robot hardware description (ros2_control hardware parameters in the URDF/xacro). These parameters are defined in the `diffbot.ros2_control.xacro` file.
- Syntax: `info_.hardware_parameters` is a map<string,string> coming from `HardwareInfo`.
- Where it's used next: These cfg\_ fields are used in `on_configure`, `read`, and `write` to talk to the microcontroller and identify joint names.
- Called again in: see `diffbot.ros2_control.xacro` where `param name="device"` etc. are set.
- Output: No runtime output, but sets up internal configuration.

```cpp
  // Encoder/ADC counts or mapping values for the actuators
  if (info_.hardware_parameters.count("link1_enc_val") > 0) {
    cfg_.link1_enc_val = std::stoi(info_.hardware_parameters["link1_enc_val"]);
  }
  if (info_.hardware_parameters.count("link2_enc_val") > 0) {
    cfg_.link2_enc_val = std::stoi(info_.hardware_parameters["link2_enc_val"]);
  }
  if (info_.hardware_parameters.count("link3_enc_val") > 0) {
    cfg_.link3_enc_val = std::stoi(info_.hardware_parameters["link3_enc_val"]);
  }
```

- What it is: Optional parameter parsing — only overwrite cfg entries if parameters exist.
- Output: numeric mapping values used by `Actuator.setup` when converting ADC counts to angles.

```cpp
  if (info_.hardware_parameters.count("pid_p") > 0)
  {
    cfg_.pid_p = std::stoi(info_.hardware_parameters["pid_p"]);
    cfg_.pid_d = std::stoi(info_.hardware_parameters["pid_d"]);
    cfg_.pid_i = std::stoi(info_.hardware_parameters["pid_i"]);
    cfg_.pid_o = std::stoi(info_.hardware_parameters["pid_o"]);
  }
  else
  {
    RCLCPP_INFO(rclcpp::get_logger("Zenorak_Hardware_Actuator"), "PID values not supplied, using defaults.");
  }
```

- What it is: PID configuration parsing. If present, store, otherwise log info and keep defaults.
- Where used: On activation the code may send PID values to the microcontroller via `comms_.set_pid_values`.

```cpp
  // Wheels removed. Only setup actuators.
  Actuator_l1.setup(cfg_.link1_name);
  Actuator_l2.setup(cfg_.link2_name);
  Actuator_l3.setup(cfg_.link3_name);
```

- What it is: Initialize actuator helper objects with the joint names from configuration.
- Where used next: Names and conversion helpers used when exporting interfaces in `export_state_interfaces` and `export_command_interfaces`.

```cpp
  // Validate joints: we expect position state interface as first state for all joints.
  // Command interface may be velocity (for wheels) or position (for actuators).
  for (const hardware_interface::ComponentInfo & joint : info_.joints)
  {
    if (joint.command_interfaces.size() != 1)
    {
      RCLCPP_FATAL(...);
      return hardware_interface::CallbackReturn::ERROR;
    }

    const auto &cmd_if = joint.command_interfaces[0].name;
    if (cmd_if != hardware_interface::HW_IF_VELOCITY && cmd_if != hardware_interface::HW_IF_POSITION)
    {
      RCLCPP_FATAL(...);
      return hardware_interface::CallbackReturn::ERROR;
    }

    if (joint.state_interfaces.size() < 1)
    {
      RCLCPP_FATAL(...);
      return hardware_interface::CallbackReturn::ERROR;
    }

    if (joint.state_interfaces[0].name != hardware_interface::HW_IF_POSITION)
    {
      RCLCPP_FATAL(...);
      return hardware_interface::CallbackReturn::ERROR;
    }

    if (joint.state_interfaces.size() > 1 && joint.state_interfaces[1].name != hardware_interface::HW_IF_VELOCITY)
    {
      RCLCPP_FATAL(...);
      return hardware_interface::CallbackReturn::ERROR;
    }
  }
```

- What it is: Sanity checks for each joint declared in the `ros2_control` system description (URDF). Ensures the hardware-exported interfaces match expectations.
- When it's called: `on_init` receives `info_.joints` from the URDF/ros2_control description (see `diffbot.ros2_control.xacro`). If joints in URDF differ, the hardware initialization fails early with clear error logs.

```cpp
  return hardware_interface::CallbackReturn::SUCCESS;
}
```

- What it is: Signal successful initialization.

---

(continued next function definitions: `try_reconnect`, `export_state_interfaces`, `export_command_interfaces`, life-cycle methods, `read`, `write`)

Below we annotate the important runtime methods.

```cpp
void Zenorak_Hardware_Actuator::try_reconnect()
{
  static rclcpp::Time last_attempt(0, 0, RCL_ROS_TIME);
  auto now = rclcpp::Clock().now();

  if ((now - last_attempt).seconds() < 2.0)
    return;

  last_attempt = now;

  try
  {
    if (comms_.connected())
      comms_.disconnect();

    std::this_thread::sleep_for(std::chrono::milliseconds(300));

    comms_.connect(cfg_.device, cfg_.baud_rate, cfg_.timeout_ms);

    RCLCPP_INFO(rclcpp::get_logger("HW"), "Actuator serial reconnected");
  }
  catch (...)
  {
    RCLCPP_WARN(rclcpp::get_logger("HW"), "Reconnect attempt failed");
  }
}
```

- What it is: Helper that tries to reconnect the serial link to the Arduino if communication is lost.
- Syntax: uses `static` to keep track of last attempt time so reconnect attempts are rate-limited to once every ~2 seconds.
- Where it's called: in `read` and `write` when `comms_.connected()` is false.
- Output: Logs success or warning messages.

```cpp
std::vector<hardware_interface::StateInterface> Zenorak_Hardware_Actuator::export_state_interfaces()
{
  std::vector<hardware_interface::StateInterface> state_interfaces;

  // Actuator position (and optional velocity) state interfaces
  state_interfaces.emplace_back(hardware_interface::StateInterface(
    Actuator_l1.name, hardware_interface::HW_IF_POSITION, &Actuator_l1.pos));
  ...
  return state_interfaces;
}
```

- What it is: This method tells ros2_control which state interfaces (position, velocity, etc.) this hardware exposes for each joint.
- Syntax: it creates `StateInterface` objects with (joint name, interface name, pointer to internal variable).
- Where used: controller_manager uses these pointers to read positions published by hardware in `read()`.
- Output: vector of StateInterface descriptors.

```cpp
std::vector<hardware_interface::CommandInterface> Zenorak_Hardware_Actuator::export_command_interfaces()
{
  std::vector<hardware_interface::CommandInterface> command_interfaces;

  command_interfaces.emplace_back(hardware_interface::CommandInterface(
    Actuator_l1.name, hardware_interface::HW_IF_POSITION, &Actuator_l1.cmd));
  ...
  return command_interfaces;
}
```

- What it is: Exposes command interfaces (where controllers will write commands). For actuators, we accept position commands.
- Where used: controllers (e.g. `joint_trajectory_controller`) will claim these command interfaces and write into these `cmd` variables.

```cpp
hardware_interface::CallbackReturn Zenorak_Hardware_Actuator::on_configure(
  const rclcpp_lifecycle::State & /*previous_state*/)
{
  RCLCPP_INFO(..., "Configuring ...please wait...");
  if (comms_.connected())
  {
    comms_.disconnect();
  }
  comms_.connect(cfg_.device, cfg_.baud_rate, cfg_.timeout_ms);
  RCLCPP_INFO(..., "Successfully configured!");

  return hardware_interface::CallbackReturn::SUCCESS;
}
```

- What it is: Lifecycle configure step — opens the serial port using the configured device and baud rate.
- Output: logs successful configuration. Returns SUCCESS if serial was opened successfully (or at least no exception thrown).

```cpp
hardware_interface::return_type Zenorak_Hardware_Actuator::read(
  const rclcpp::Time & /*time*/, const rclcpp::Duration & period)
{
  if (!comms_.connected())
  {
  try_reconnect();
  return hardware_interface::return_type::OK;
  }

  double delta_seconds = period.seconds();

  int a1 = 0, a2 = 0, a3 = 0;
  comms_.read_actuator_values(a1, a2, a3);

  double prev_pos;

  // Actuator 1
  prev_pos = Actuator_l1.pos;
  Actuator_l1.raw_count = a1;
  Actuator_l1.pos = Actuator_l1.potToAngle(
    a1,
    0.0, 80.0,     // logical angle range
    460, 730       // pot range
  );
  Actuator_l1.vel = (Actuator_l1.pos - prev_pos) / delta_seconds;

  ... (actuator 2 and 3 handled similarly)

  RCLCPP_INFO(..., "Arm pos: %f %f %f", Actuator_l1.pos, Actuator_l2.pos, Actuator_l3.pos);

  return hardware_interface::return_type::OK;
}
```

- What it is: Called periodically by controller_manager to fetch the latest hardware state and update the exported state interface variables.
- Input: `period` gives the time since last call. Used to compute velocities.
- Steps:
  - If serial not connected, try reconnect and return OK (no state change).
  - Read raw actuator counts from Arduino via `comms_`.
  - Convert raw counts to logical joint angles using `Actuator::potToAngle`.
  - Compute velocities based on position delta and `period`.
- Output: updates `Actuator_lX.pos` and `.vel` in-place (these are the state interface targets that controllers or broadcasters read).
- Called by: controller_manager main loop.

```cpp
hardware_interface::return_type zenorak_controller_actuator ::Zenorak_Hardware_Actuator::write(
  const rclcpp::Time & /*time*/, const rclcpp::Duration & /*period*/)
{
  if (!comms_.connected())
  {
  try_reconnect();
  return hardware_interface::return_type::OK;
  }

  int a1_target = Actuator_l1.angleToPot(
    Actuator_l1.cmd,
    0.0, 80.0,     // angle range in degrees
    460, 730        // pot range
  );
  ... (a2_target, a3_target)

  comms_.set_actuator_positions(a1_target, a2_target, a3_target);
  return hardware_interface::return_type::OK;
}
```

- What it is: Called periodically and sends the latest command values to the microcontroller.
- Input: `Actuator_lX.cmd` is written by the controller that claims the `CommandInterface` (e.g. `joint_trajectory_controller`).
- Output: Sends an `s v1 v2 v3\r` message to the Arduino via `ArduinoComms::set_actuator_positions`.

---

Where functions/variables are used across the package (quick cross-reference):

- `cfg_.device`, `cfg_.baud_rate`, `cfg_.timeout_ms` are set in `on_init` and used in `on_configure` to open serial in `comms_.connect`.
- `Actuator_lX` objects are declared in `diffbot_system.hpp` and their methods are defined in `Actuator.hpp` (see annotated file for the Actuator class).
- `comms_.read_actuator_values` and `comms_.set_actuator_positions` are defined in `arduino_comms.hpp`.
- The hardware plugin is referenced in `description/ros2_control/diffbot.ros2_control.xacro` via the `<plugin>` tag.

Production summary (child-friendly):

- This file is the bridge between ROS controllers and the robot hardware (Arduino). It reads sensor values (potentiometer counts) and tells ROS what the joint angles are, and it receives position commands from controllers and sends them to the Arduino. It checks and opens the serial port, converts raw counts into angles, and keeps everything synchronized with the ROS controller loop.

If you'd like, I can now create the same kind of annotated file for the other headers and launch/config files and then write a friendly, step-by-step README explaining how to build, run, and integrate this package into URDF/xacro with ros2_control.

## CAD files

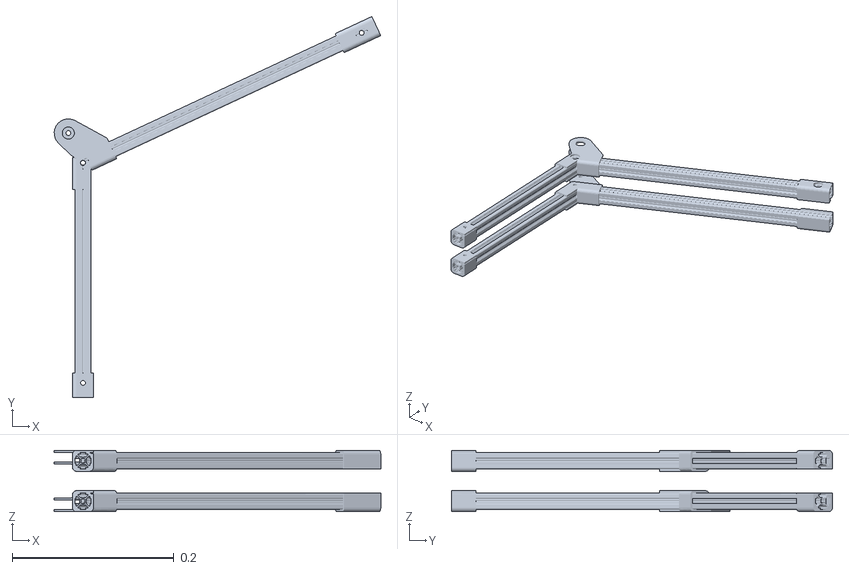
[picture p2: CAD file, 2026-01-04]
zenorak_ros2_control/meshes/linkk_1_part.STL
0.404 x 0.471 x 0.076

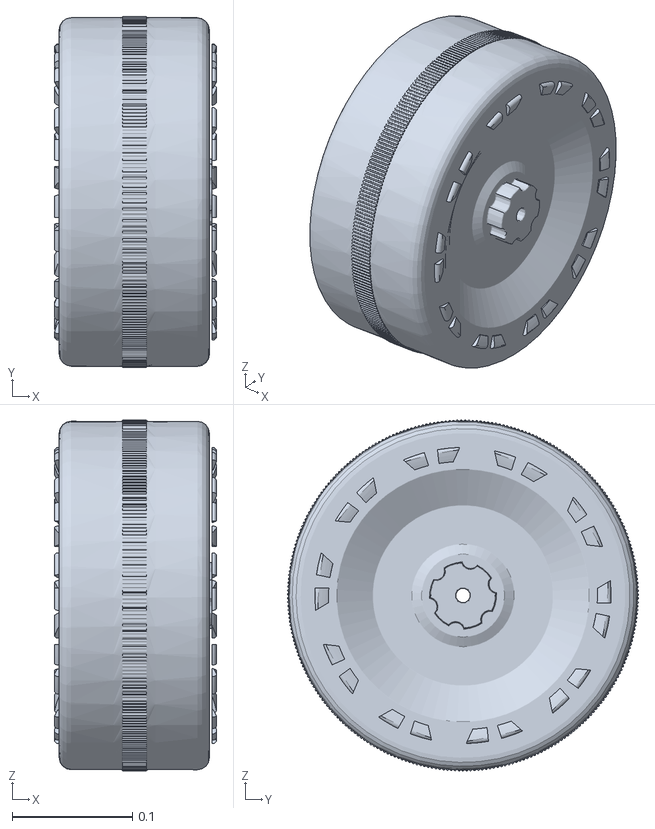
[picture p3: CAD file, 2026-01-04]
zenorak_ros2_control/meshes/front_wheel_right_part.STL
0.135 x 0.292 x 0.292

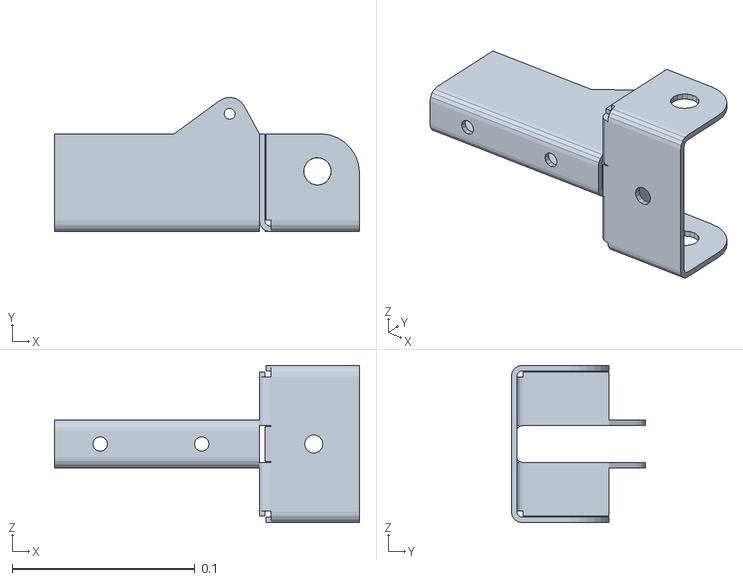
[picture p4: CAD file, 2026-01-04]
zenorak_ros2_control/meshes/manipulator_base_part.STL
0.167 x 0.0735 x 0.086

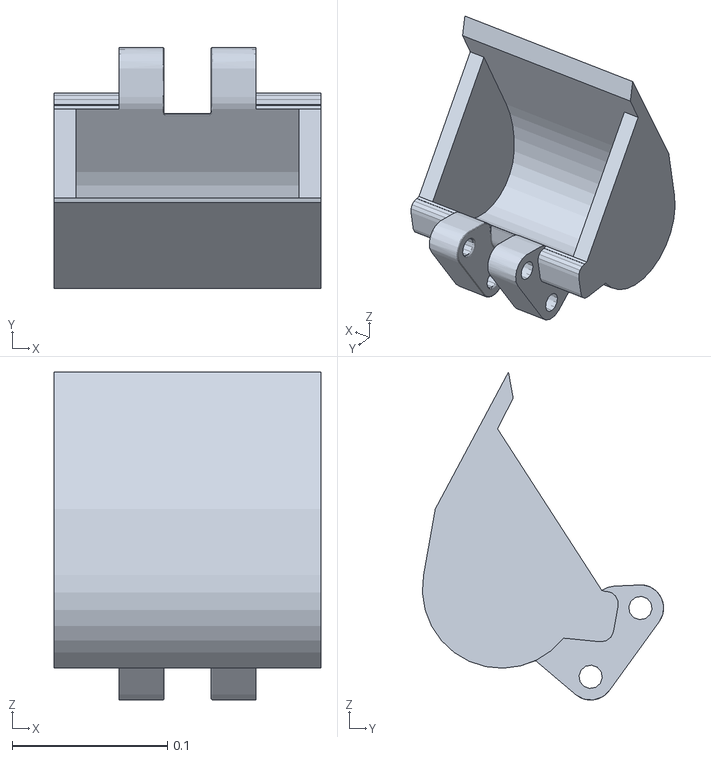
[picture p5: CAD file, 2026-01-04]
zenorak_ros2_control/meshes/link_3_part.STL
0.172 x 0.155 x 0.211

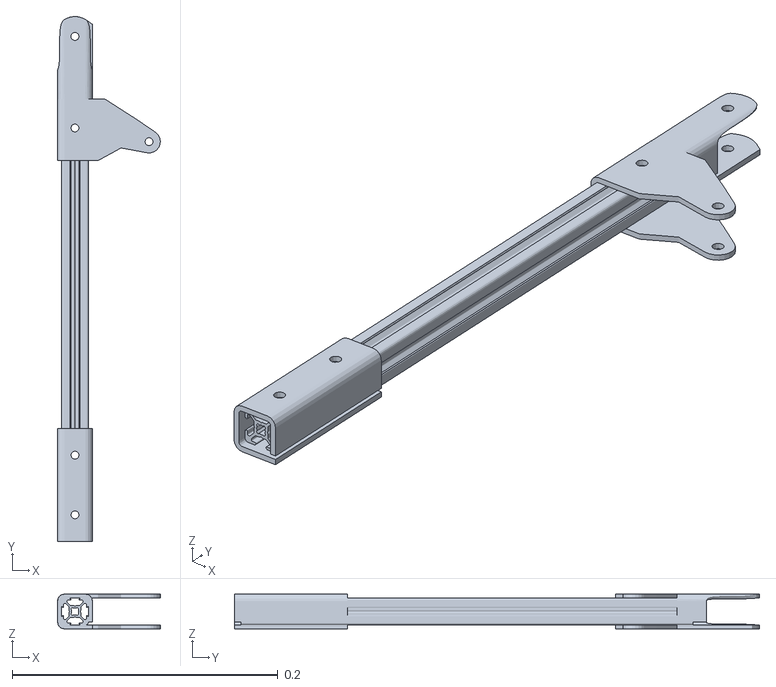
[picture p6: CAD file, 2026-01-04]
zenorak_ros2_control/meshes/link_2_part.STL
0.0773 x 0.395 x 0.026

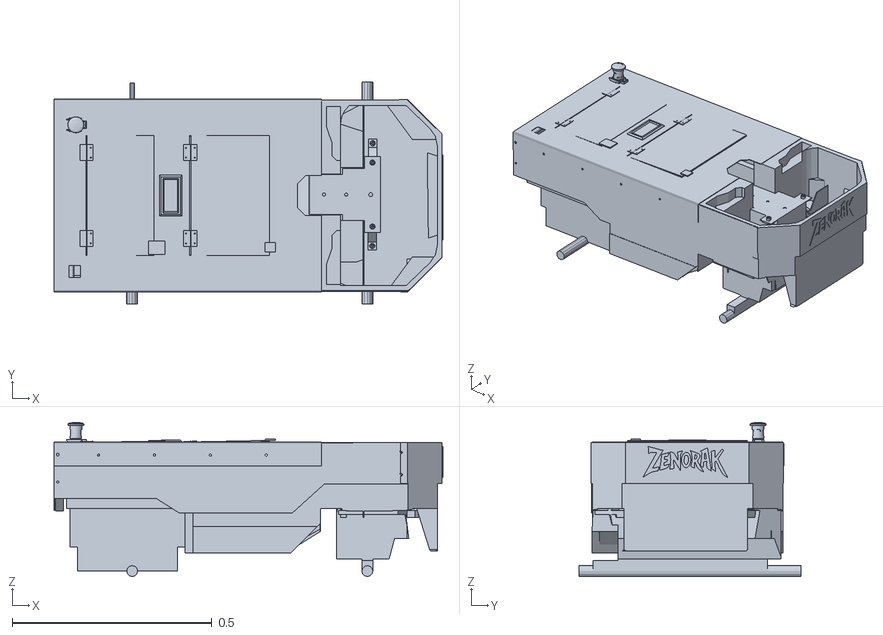
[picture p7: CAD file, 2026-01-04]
zenorak_ros2_control/meshes/base_link.STL
0.974 x 0.557 x 0.386

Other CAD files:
zenorak_ros2_control/meshes/rear_wheel_left_part.STL
zenorak_ros2_control/meshes/rear_wheel_right_part.STL
zenorak_ros2_control/meshes/front_wheel_left_part.STL

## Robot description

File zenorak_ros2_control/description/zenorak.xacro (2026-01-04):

<?xml version="1.0" encoding="utf-8"?>

<robot name="zenorak_ros2_control" xmlns:xacro="http://www.ros.org/wiki/xacro">

    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
    <xacro:arg name="is_ignition" default="true"/>

    <link name="base_footprint"/>
    <joint name="base_footprint_part" type="fixed">
        <origin xyz="-0.4763649 0.3169183 0.179" rpy="0 0 0"/>
        <parent link="base_footprint"/>
        <child link="base_link"/>
    </joint>


    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

    <link name="base_link">
        <inertial>
            <origin xyz="0.225609050013199 -0.382431512154995 0.110457297768854" rpy="0 0 0" />
            <mass value="37.6020822567643" />
            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
        </inertial>
        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
    </link>
    <link name="rear_wheel_left_part">
        <inertial>
            <origin xyz="-0.0679260215961148 2.36125695066147E-07 -1.94731959117164E-06" rpy="0 0 0" />
            <mass value="7.07873349857202" />
            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
        </inertial>
        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
    </link>
    <joint name="rear_wheel_left" type="continuous">
        <origin xyz="-0.112759182276568 -0.562875460951289 -0.0350858656525844" rpy="3.0811708109372 0 1.5707963267949" />
        <parent link="base_link" />
        <child link="rear_wheel_left_part" />
        <axis xyz="1 0 0" />
    </joint>
    <link name="rear_wheel_right_part">
        <inertial>
            <origin xyz="0.0703369302084167 -2.36126483657562E-07 -1.94731702234455E-06" rpy="0 0 0" />
            <mass value="7.07873349872348" />
            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
        </inertial>
        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
    </link>
    <joint name="rear_wheel_right" type="continuous">
        <origin xyz="-0.112759182276568 -0.0709611226931948 -0.0350858656525845" rpy="-3.0811708109372 0 -1.5707963267949" />
        <parent link="base_link" />
        <child link="rear_wheel_right_part" />
        <axis xyz="-1 0 0" />
    </joint>
    <link name="front_wheel_left_part">
        <inertial>
            <origin xyz="-0.0679260215959383 -1.30981837787036E-06 1.46020001273728E-06" rpy="0 0 0" />
            <mass value="7.07873349856122" />
            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
        </inertial>
        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
    </link>
    <joint name="front_wheel_left" type="continuous">
        <origin xyz="0.476364897342864 -0.562875460951289 -0.0350858656525772" rpy="-1.93646547797082 0 1.5707963267949" />
        <parent link="base_link" />
        <child link="front_wheel_left_part" />
        <axis xyz="1 0 0" />
    </joint>
    <link name="front_wheel_right_part">
        <inertial>
            <origin xyz="0.0703369302085943 1.30981749479897E-06 1.46019747881976E-06" rpy="0 0 0" />
            <mass value="7.07873349871121" />
            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
        </inertial>
        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
    </link>
    <joint name="front_wheel_right" type="continuous">
        <origin xyz="0.476364897342864 -0.0709611226931948 -0.0350858656525772" rpy="1.93646547797082 0 -1.5707963267949" />
        <parent link="base_link" />
        <child link="front_wheel_right_part" />
        <axis xyz="1 0 0" />
    </joint>

    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
    <xacro:property name="PI" value="3.14159265359" />
    <xacro:property name="effort" value="30.0" />
    <xacro:property name="velocity" value="10.0" />




    <link name="manipulator_base_part">
        <inertial>
            <origin xyz="0.157263621201152 0.101352922065795 1.87079851471372E-06" rpy="0 0 0"/>
            <mass value="2.2590906062532"/>
            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
        </inertial>

        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
    </link>

    <joint name="manipulator_base" type="fixed">
        <origin xyz="0.285562617252501 -0.383543373894075 0.122214368843715" rpy="1.5707963267949 0 0"/>
        <parent link="base_link"/>
        <child link="manipulator_base_part"/>
        <axis xyz="0 0 0"/>
    </joint>

    <link name="linkk_1_part">
        <inertial>
            <origin xyz="0.0967880608316517 0.260782714993558 5.34841523558427E-06" rpy="0 0 0"/>
            <mass value="0.305707588406735"/>
            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
        </inertial>

        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
    </link>

    <joint name="linkk_1" type="revolute">
        <origin xyz="0.201025284688791 0.11855300220073 0" rpy="0 0 -0.285822234578718"/>
        <parent link="manipulator_base_part"/>
        <child link="linkk_1_part"/>
        <axis xyz="0 0 1"/>
        <limit lower="${0.001}" upper="-${0.8}" effort="${effort}" velocity="${velocity}"/>
    </joint>

    <link name="link_2_part">
        <inertial>
            <origin xyz="0.00878775849458302 -0.0734961309869713 2.07355477566118E-07" rpy="0 0 0"/>
            <mass value="0.175654601701013"/>
            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
        </inertial>

        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
    </link>

    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
    <joint name="link_2" type="revolute">
        <origin xyz="0.344393779505362 0.432597470756819 0" rpy="0 0 1.10459913734809"/>
        <parent link="linkk_1_part"/>
        <child link="link_2_part"/>
        <axis xyz="0 0 1"/>
        <limit lower="${0.195}" upper="-${1.129}" effort="${effort}" velocity="${velocity}"/>
    </joint>

    <link name="link_3_part">
        <inertial>
            <origin xyz="1.89394355052941E-05 -0.0795967370189372 0.0218929431451993" rpy="0 0 0"/>
            <mass value="1.1744727454073"/>
            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
        </inertial>

        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
    </link>

    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
    <joint name="link_3" type="revolute">
        <origin xyz="0 -0.291104719303414 0" rpy="2.3649900417239 -1.5707963267949 0"/>
        <parent link="link_2_part"/>
        <child link="link_3_part"/>
        <axis xyz="1 0 0"/>
        <limit lower="-${1.25664}" upper="-${2.87979}" effort="${effort}" velocity="${velocity}"/>
    </joint>


    <ros2_control name="zenorak_motor_hw" type="system">
        <hardware>
            <plugin>zenorak_controller_motor/Zenorak_Hardware_Motor</plugin>
            <param name="left_wheel_name">front_wheel_left</param>
            <param name="right_wheel_name">front_wheel_right</param>
            <param name="loop_rate">30</param>
            <param name="device">/dev/serial/by-path/platform-3610000.usb-usb-0:2.1:1.0</param>
            <param name="baud_rate">115200</param>
            <param name="timeout_ms">1000</param>
            <param name="enc_counts_per_rev">3000</param>
        </hardware>

        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
        <joint name="front_wheel_left">
            <command_interface name="velocity"/>
            <state_interface name="position"/>
            <state_interface name="velocity"/>
        </joint>
        <joint name="front_wheel_right">
            <command_interface name="velocity"/>
            <state_interface name="position"/>
            <state_interface name="velocity"/>
        </joint>

    </ros2_control>
    <ros2_control name="zenorak_actuator_hw" type="system">
        <hardware>
            <plugin>zenorak_controller_actuator/Zenorak_Hardware_Actuator</plugin>
            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
            <param name="device">/dev/serial/by-path/platform-3610000.usb-usb-0:2.4:1.0</param>
            <param name="baud_rate">115200</param>
            <param name="timeout_ms">1000</param>
            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
            <param name="pid_p">20</param>
            <param name="pid_d">12</param>
            <param name="pid_i">0</param>
            <param name="pid_o">50</param>
            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
            <param name="link1_name">linkk_1</param>
            <param name="link2_name">link_2</param>
            <param name="link3_name">link_3</param>
            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
            <param name="link1_enc_val">1023</param>
            <param name="link2_enc_val">1023</param>
            <param name="link3_enc_val">1023</param>
        </hardware>
        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
        <joint name="linkk_1">
            <command_interface name="position"/>
            <state_interface name="position"/>
        </joint>

        <joint name="link_2">
            <command_interface name="position"/>
            <state_interface name="position"/>
        </joint>

        <joint name="link_3">
            <command_interface name="position"/>
            <state_interface name="position"/>
        </joint>
    </ros2_control>

</robot>

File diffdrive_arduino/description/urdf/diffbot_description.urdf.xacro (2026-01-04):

<?xml version="1.0"?>
<robot xmlns:xacro="http://www.ros.org/wiki/xacro">

  <xacro:macro name="diffbot" params="prefix">

  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
  <xacro:property name="PI" value="3.1415926535897931"/>
  <xacro:property name="base_mass" value="0.3" /> 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
  <xacro:property name="base_width" value="0.1" />
  <xacro:property name="base_length" value="0.1" />
  <xacro:property name="base_height" value="0.05" />
  <xacro:property name="wheel_mass" value="0.3" /> 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
  <xacro:property name="wheel_len" value="0.020" />
  <xacro:property name="wheel_radius" value="0.015" />
  <xacro:property name="caster_wheel_mass" value="0.1" /> 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
  <xacro:property name="caster_wheel_radius" value="0.015" />
  <xacro:property name="z_offset" value="-${base_height/2}" /> 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
  <link name="${prefix}base_link">
    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

    <inertial>
      <origin xyz="0 0 0" rpy="0 0 0"/>
      <mass value="${base_mass}"/>
      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
      </inertial>
    </link>

    <joint name="${prefix}left_wheel_joint" type="continuous">
      <parent link="${prefix}base_link"/>
      <child link="${prefix}left_wheel"/>
      <origin xyz="0 -${base_width/2} ${z_offset}" rpy="0 0 0"/>
      <axis xyz="0 1 0"/>
      <dynamics damping="0.2"/>
    </joint>

    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
    <link name="${prefix}left_wheel">
      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

      <inertial>
        <origin xyz="0 0 0" rpy="${PI/2} 0 0"/>
        <mass value="${wheel_mass}"/>
        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
        </inertial>
      </link>

    <joint name="${prefix}right_wheel_joint" type="continuous">
      <parent link="${prefix}base_link"/>
      <child link="${prefix}right_wheel"/>
      <origin xyz="0 ${base_width/2} ${z_offset}" rpy="0 0 0"/>
      <axis xyz="0 1 0"/>
      <dynamics damping="0.2"/>
    </joint>

    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
    <link name="${prefix}right_wheel">
      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

      <inertial>
        <origin xyz="0 0 0" rpy="${PI/2} 0 0"/>
        <mass value="${wheel_mass}"/>
        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
        </inertial>
      </link>

    <joint name="${prefix}caster_frontal_wheel_joint" type="fixed">
      <parent link="${prefix}base_link"/>
      <child link="${prefix}caster_frontal_wheel"/>
      <origin xyz="${base_width/2 - caster_wheel_radius} 0 ${z_offset}" rpy="0 0 0"/>
    </joint>

    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
    <link name="${prefix}caster_frontal_wheel">
      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

      <inertial>
        <origin xyz="0 0 0" rpy="0 0 0"/>
        <mass value="${caster_wheel_mass}"/>
        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
        </inertial>
      </link>

    <joint name="${prefix}caster_rear_wheel_joint" type="fixed">
      <parent link="${prefix}base_link"/>
      <child link="${prefix}caster_rear_wheel"/>
      <origin xyz="${-base_width/2 + caster_wheel_radius} 0 ${z_offset}" rpy="0 0 0"/>
    </joint>

    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
    <link name="${prefix}caster_rear_wheel">
      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

      <inertial>
        <origin xyz="0 0 0" rpy="0 0 0"/>
        <mass value="${caster_wheel_mass}"/>
        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
        </inertial>
      </link>

  </xacro:macro>

</robot>

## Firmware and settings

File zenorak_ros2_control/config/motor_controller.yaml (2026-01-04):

controller_manager:
  ros__parameters:
    update_rate: 100
    # use_sim_time: true

    diff_cont:
      type: diff_drive_controller/DiffDriveController

    joint_broad:
      type: joint_state_broadcaster/JointStateBroadcaster

diff_cont:
  ros__parameters:
    publish_rate: 100.0

    base_frame_id: base_link

    left_wheel_names: ["front_wheel_left"]
    right_wheel_names: ["front_wheel_right"]
    wheel_separation: 0.40
    wheel_radius: 0.14

    use_stamped_vel: false
    base_frame_id: base_footprint
    enable_odom_tf: true

    # open_loop: false

    # wheels_per_side: x
    # wheel_separation_multiplier: x
    # left_wheel_radius_multiplier: x
    # right_wheel_radius_multiplier: x

    # odom_frame_id: x
    # pose_covariance_diagonal: x
    # twist_covariance_diagonal: x
    # open_loop: x
    # enable_odom_tf: x

    # cmd_vel_timeout: x
    # publish_limited_velocity: x
    # velocity_rolling_window_size: x

    # linear.x.has_velocity_limits: false
    # linear.x.has_acceleration_limits: false
    # linear.x.has_jerk_limits: false
    # linear.x.max_velocity: NAN
    # linear.x.min_velocity: NAN
    # linear.x.max_acceleration: NAN
    # linear.x.min_acceleration: NAN
    # linear.x.max_jerk: NAN
    # linear.x.min_jerk: NAN

    # angular.z.has_velocity_limits: false
    # angular.z.has_acceleration_limits: false
    # angular.z.has_jerk_limits: false
    # angular.z.max_velocity: NAN
    # angular.z.min_velocity: NAN
    # angular.z.max_acceleration: NAN
    # angular.z.min_acceleration: NAN
    # angular.z.max_jerk: NAN
    # angular.z.min_jerk: NAN
    # joint_broad:
    #   ros__parameters:
    state_interfaces: # Interfaces for feedback/state reporting
      - position # Reports current joint positions
      - velocity # Reports current joint velocities
    command_interfaces: # Interfaces used for sending commands
      - position # Controller sends desired joint positions

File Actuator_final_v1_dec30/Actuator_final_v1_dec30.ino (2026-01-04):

// Core Arduino functions (Serial, pinMode, attachInterrupt, millis, etc.)
#include <Arduino.h>
// Cytron motor driver helper to control CytronMD motor objects
#include "CytronMotorDriver.h"

/* ================= CONFIG ================= */
// Serial baud rate for communication with host
#define BAUDRATE 115200
// Dead band for actuator target vs current pot reading (avoid chatter)
#define DEAD_BAND 20
// Main loop delta time in milliseconds (polling rate for actuators)
#define LOOP_DT 5   // ms (fast enough for ROS)

/* ================= MOTORS ================= */
// Motor driver objects: (mode, PWM pin, DIR pin)
CytronMD motor1(PWM_DIR, 3, 42);
CytronMD motor2(PWM_DIR, 2, 40);
CytronMD motor3(PWM_DIR, 5, 38);
CytronMD motor4(PWM_DIR, 4, 36);

/* ================= ENCODERS ================= */
// Encoder input pins
#define ENC1 18
#define ENC2 19
#define ENC3 20
#define ENC4 21

// Volatile counters incremented by ISRs on encoder events
volatile long count1 = 0;
volatile long count2 = 0;
volatile long count3 = 0;
volatile long count4 = 0;

/* ================= ACTUATORS ================= */
// Actuator representation: pins for extend/retract, analog pot pin, pot min/max calibration,
// current target pot value, and whether the actuator is actively moving toward target.
struct Actuator {
  int extendPin;
  int retractPin;
  int potPin;
  int potMin;
  int potMax;
  int target;
  bool active;
};
  // extend, retract, pot,  min, max, target, active

// Array of three actuators with pin mappings and calibration values
Actuator actuators[3] = {
  {2, 3, A0,  460, 700, 460, false},
  {4, 5, A1,  150, 500, 150, false},
  {6, 7, A2,  85, 470,  85, false}
};

/* ================= ISR ================= */
// Simple ISRs: increment encoder counters on each triggered edge
void isr1(){ count1++; }
void isr2(){ count2++; }
void isr3(){ count3++; }
void isr4(){ count4++; }

/* ================= HELPERS ================= */
// Read actuator potentiometer and clamp to calibrated min/max range
inline int readPot(Actuator &a) {
  return constrain(analogRead(a.potPin), a.potMin, a.potMax);
}

// Stop movement of a single actuator by disabling both drive pins
inline void stopActuator(Actuator &a) {
  digitalWrite(a.extendPin, LOW);
  digitalWrite(a.retractPin, LOW);
}

// Drive actuator to extend: set extend pin HIGH, retract LOW
inline void extendActuator(Actuator &a) {
  digitalWrite(a.extendPin, HIGH);
  digitalWrite(a.retractPin, LOW);
}

// Drive actuator to retract: set retract pin HIGH, extend LOW
inline void retractActuator(Actuator &a) {
  digitalWrite(a.extendPin, LOW);
  digitalWrite(a.retractPin, HIGH);
}

// Set motor speeds for left and right sides (clamp inputs and apply to both motors per side)
inline void setMotors(int left, int right) {
  left  = constrain(left,  -255, 255);
  right = constrain(right, -255, 255);

  motor1.setSpeed(left);
  motor2.setSpeed(left);
  motor3.setSpeed(right);
  motor4.setSpeed(right);
}

/* ================= SERIAL ================= */
// Simple serial command interface. Single-character commands followed by numeric args where applicable.
// Commands supported:
//  'm' <left> <right>    -> set motor speeds
//  's' <t0> <t1> <t2>    -> set actuator targets (pot values)
//  'e'                   -> request encoder counts (returns "<left> <right>\n")
//  'a'                   -> request actuator pot readings (returns "p0 p1 p2\n")
void handleSerial()
{
  if (!Serial.available()) return;

  char cmd = Serial.read();

  /* MOTOR COMMAND */
  if (cmd == 'm') {
    int l = Serial.parseInt();
    int r = Serial.parseInt();
    setMotors(l, r);
  }

  // Set actuator target positions for all 3 actuators
  else if (cmd == 's') {
    for (int i = 0; i < 3; i++) {
      int t = Serial.parseInt();
      // clamp incoming target to calibrated pot range
      t = constrain(t, actuators[i].potMin, actuators[i].potMax);

      int current = readPot(actuators[i]);

      // Only activate movement if the requested target differs by more than DEAD_BAND
      if (abs(t - current) > DEAD_BAND) {
        actuators[i].target = t;
        actuators[i].active = true;
      }
    }
}

  /* ENCODERS (ALWAYS RESPOND) */
  else if (cmd == 'e') {
    long left  = (count1 + count2) / 2;
    long right = (count3 + count4) / 2;
    Serial.print(left);
    Serial.print(" ");
    Serial.print(right);
    Serial.print("\n");
  }

  /* ACTUATORS FEEDBACK (ALWAYS RESPOND) */
  else if (cmd == 'a') {
    // Print current potentiometer readings for each actuator
    Serial.print(readPot(actuators[0]));
    Serial.print(" ");
    Serial.print(readPot(actuators[1]));
    Serial.print(" ");
    Serial.print(readPot(actuators[2]));
    Serial.print("\n");
  }

  // Clear any remaining bytes in the Serial buffer for this command cycle
  while (Serial.available()) Serial.read();
}

/* ================= ACTUATOR LOOP ================= */
// Called repeatedly to drive an active actuator toward its target pot reading.
void updateActuator(Actuator &a)
{
  if (!a.active) return;

  int pos = readPot(a);
  int err = a.target - pos;

  // If within dead band, stop and mark inactive
  if (abs(err) <= DEAD_BAND) {
    stopActuator(a);
    a.active = false;
    return;
  }

  // Drive in the correct direction based on sign of error
  if (err > 0) extendActuator(a);
  else retractActuator(a);
}

/* ================= SETUP ================= */
void setup()
{
  // Initialize serial for host communication
  Serial.begin(BAUDRATE);

  // Configure encoder pins with internal pull-ups
  pinMode(ENC1, INPUT_PULLUP);
  pinMode(ENC2, INPUT_PULLUP);
  pinMode(ENC3, INPUT_PULLUP);
  pinMode(ENC4, INPUT_PULLUP);

  // Attach ISRs for encoder counting on FALLING edges
  attachInterrupt(digitalPinToInterrupt(ENC1), isr1, FALLING);
  attachInterrupt(digitalPinToInterrupt(ENC2), isr2, FALLING);
  attachInterrupt(digitalPinToInterrupt(ENC3), isr3, FALLING);
  attachInterrupt(digitalPinToInterrupt(ENC4), isr4, FALLING);

  // Configure actuator control pins and ensure actuators are stopped
  for (int i = 0; i < 3; i++) {
    pinMode(actuators[i].extendPin, OUTPUT);
    pinMode(actuators[i].retractPin, OUTPUT);
    stopActuator(actuators[i]);
  }

  // Signal ready to host
  Serial.println("ZENORAK READY");
}

/* ================= LOOP ================= */
void loop()
{
  // Always process serial commands first for responsiveness
  handleSerial();   // ALWAYS FIRST

  // Simple fixed-rate loop using millis() and LOOP_DT to schedule actuator updates
  static unsigned long last = 0;
  unsigned long now = millis();
  if (now - last < LOOP_DT) return;
  last = now;

  // Update each actuator (move toward target if active)
  for (int i = 0; i < 3; i++)
    updateActuator(actuators[i]);
}

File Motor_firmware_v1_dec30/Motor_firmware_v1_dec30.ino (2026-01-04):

// Include core Arduino API (digital/analog, Serial, pinMode, attachInterrupt, etc.)
#include <Arduino.h>
// Include Cytron motor driver helper to control CytronMD objects
#include "CytronMotorDriver.h"

/* ================= CONFIG ================= */
// Define serial baud rate used for Serial communication with the host
#define BAUDRATE 115200

/* ================= MOTORS ================= */
// Using CytronMD in PWM_DIR mode: first arg selects mode, next two are PWM and DIR pins
// Front-left motor object (PWM pin 3, DIR pin 42)
CytronMD motorFL(PWM_DIR, 3, 42);  // Front Left
// Rear-left motor object (PWM pin 2, DIR pin 40)
CytronMD motorRL(PWM_DIR, 2, 40);  // Rear Left
// Front-right motor object (PWM pin 5, DIR pin 38)
CytronMD motorFR(PWM_DIR, 5, 38);  // Front Right
// Rear-right motor object (PWM pin 4, DIR pin 36)
CytronMD motorRR(PWM_DIR, 4, 36);  // Rear Right

/* ================= ENCODERS ================= */
// Encoder input pin definitions (one pin per encoder channel used here)
#define ENC_FL 18
#define ENC_RL 19
#define ENC_FR 20
#define ENC_RR 21

// Volatile counters for encoder ticks; volatile because updated inside ISRs
volatile long encFL = 0;
volatile long encRL = 0;
volatile long encFR = 0;
volatile long encRR = 0;

/* ================= ISR ================= */
// Interrupt Service Routines: each is called on the encoder signal edge and increments its counter
void isrFL() { encFL++; }
void isrRL() { encRL++; }
void isrFR() { encFR++; }
void isrRR() { encRR++; }

/* ================= MOTOR CONTROL ================= */
// Helper to set left/right motor speeds. Values are clamped to valid PWM range.
inline void setMotors(int left, int right)
{
  // Clamp inputs to [-255, 255] where the Cytron driver expects signed speed values
  left  = constrain(left,  -255, 255);
  right = constrain(right, -255, 255);

  // Apply the left speed to both left-side motors
  motorFL.setSpeed(left);
  motorRL.setSpeed(left);
  // Apply the right speed to both right-side motors
  motorFR.setSpeed(right);
  motorRR.setSpeed(right);
}

/* ================= SERIAL PARSER ================= */
// Fast, non-blocking, CR-terminated command parser.
// Supported commands:
//   m<left> <right>\r   -> set motor speeds (integers)
//   e\r                 -> request encoder counts (returns "<left> <right>\n")
char rxBuf[32];          // buffer for incoming command characters
uint8_t rxIndex = 0;     // current write index into rxBuf

void handleSerial()
{
  // Read all available characters from Serial (non-blocking)
  while (Serial.available())
  {
    char c = Serial.read();

    // If we get a carriage-return, treat it as end-of-command
    if (c == '\r')
    {
      // Null-terminate received string and reset index for next command
      rxBuf[rxIndex] = '\0';
      rxIndex = 0;

      // ---- MOTOR COMMAND (starts with 'm') ----
      if (rxBuf[0] == 'm')
      {
        int l = 0, r = 0;
        // Parse two integers after the 'm'
        sscanf(rxBuf + 1, "%d %d", &l, &r);
        // Set motor speeds (left, right)
        setMotors(l, r);
      }

      // ---- ENCODER REQUEST (starts with 'e') ----
      else if (rxBuf[0] == 'e')
      {
        // Disable interrupts briefly to read multi-byte volatile counters safely
        noInterrupts();
        long left  = (encFL + encRL) / 2;   // average left side encoders
        long right = (encFR + encRR) / 2;   // average right side encoders
        interrupts();

        // Send encoder counts as text: "<left> <right>\n"
        Serial.print(left);
        Serial.print(' ');
        Serial.print(right);
        Serial.print('\n');
      }
    }
    else
    {
      // Accumulate character into buffer if there is space (leave room for NUL)
      if (rxIndex < sizeof(rxBuf) - 1)
        rxBuf[rxIndex++] = c;
    }
  }
}

/* ================= SETUP ================= */
void setup()
{
  // Initialize serial at configured baud rate for communication with host
  Serial.begin(BAUDRATE);

  // Configure encoder pins as inputs with internal pull-ups enabled
  pinMode(ENC_FL, INPUT_PULLUP);
  pinMode(ENC_RL, INPUT_PULLUP);
  pinMode(ENC_FR, INPUT_PULLUP);
  pinMode(ENC_RR, INPUT_PULLUP);

  // Attach interrupt handlers for each encoder pin on the FALLING edge
  attachInterrupt(digitalPinToInterrupt(ENC_FL), isrFL, FALLING);
  attachInterrupt(digitalPinToInterrupt(ENC_RL), isrRL, FALLING);
  attachInterrupt(digitalPinToInterrupt(ENC_FR), isrFR, FALLING);
  attachInterrupt(digitalPinToInterrupt(ENC_RR), isrRR, FALLING);

  // Ensure motors are stopped at startup
  setMotors(0, 0);

  // Notify host that the motor controller is ready
  Serial.println("ZENORAK MOTOR READY");
}

/* ================= LOOP ================= */
void loop()
{
  // No delay here: repeatedly call handleSerial() to be responsive to commands
  handleSerial();
}

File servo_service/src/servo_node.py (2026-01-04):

#!/usr/bin/env python3

import rclpy
from rclpy.node import Node
from servo_service.srv import SetServoAngle
import Jetson.GPIO as GPIO
import time

SERVO_PIN = 32          # PWM pin (change if needed)
PWM_FREQ = 50           # 50Hz for servo

class ServoService(Node):

    def __init__(self):
        super().__init__('servo_service_node')

        # ROS service
        self.srv = self.create_service(
            SetServoAngle,
            'set_servo_angle',
            self.set_servo_callback
        )

        # GPIO setup
        GPIO.setmode(GPIO.BOARD)
        GPIO.setup(SERVO_PIN, GPIO.OUT)

        self.pwm = GPIO.PWM(SERVO_PIN, PWM_FREQ)
        self.pwm.start(0)

        self.get_logger().info("Servo service ready")

    def angle_to_duty(self, angle):
        # 0° → ~2.5%, 180° → ~12.5%
        return 2.5 + (angle / 180.0) * 10.0

    def set_servo_callback(self, request, response):
        angle = max(0, min(180, request.angle))
        duty = self.angle_to_duty(angle)

        self.get_logger().info(f"Moving servo to {angle}°")

        self.pwm.ChangeDutyCycle(duty)
        time.sleep(0.5)
        self.pwm.ChangeDutyCycle(0)

        response.success = True
        response.message = f"Servo moved to {angle} degrees"
        return response

    def destroy_node(self):
        self.pwm.stop()
        GPIO.cleanup()
        super().destroy_node()


def main():
    rclpy.init()
    node = ServoService()
    try:
        rclpy.spin(node)
    except KeyboardInterrupt:
        pass
    node.destroy_node()
    rclpy.shutdown()

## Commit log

2025-09-08 updated frequecy to 1hz AND added watchdog timer to firmware and also added buffer for storage and running
2025-09-18 test_ros2control new branch
    [base_link.STL, controller.yaml, front_left_wheel.STL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]
2025-09-19 working ros2_control
    [controller.yaml, ros2_control.xacro, zenorak.xacro]
2025-12-30 Manipulator and motor control with 2 arduinos
    [actuator_controller.yaml, base_link.STL, diffbot.materials.xacro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]
2025-12-30 added firmware and added readme for autonomous team with sample scripts
2026-01-01 Add arm joystick controller to launch file
2026-01-02 pin change
2026-01-02 servo and force sensor and then link1 calib values
2026-01-03 joyatick yaw
